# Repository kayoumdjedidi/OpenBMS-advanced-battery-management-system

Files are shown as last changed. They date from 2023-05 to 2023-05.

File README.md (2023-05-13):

# OpenBMS: Open Source advanced Battery Management System

OpenBMS is an open source battery management system (BMS) for lithium-ion and other types of batteries up to 12V and 20V total voltage. The system monitors battery status, charges the battery as required, and most importantly, balances the cells to ensure longer lifespan and protection against undervolting. The system is suitable for various applications, including electric vehicles, renewable energy systems, and portable electronics.

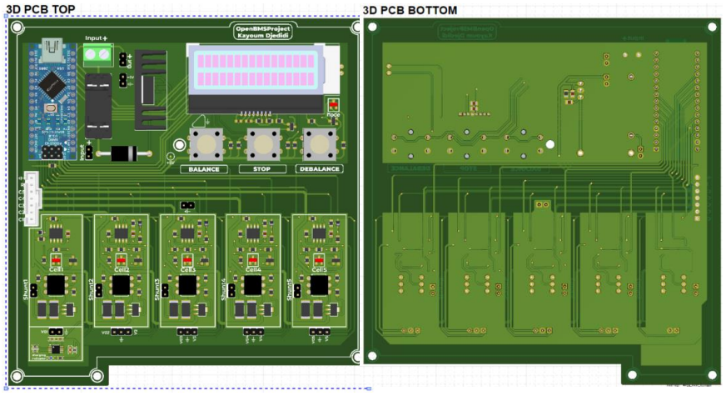
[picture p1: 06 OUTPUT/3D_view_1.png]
Preview image


## Table of Contents

- [Introduction](#openbms-open-source-battery-management-system)
- [Table of Contents](#table-of-contents)
- [Features](#features)
- [Documentation](#documentation)
- [Hardware Design](#hardware-design)
- [Software Design](#software-design)
- [Limitations and Future Improvements](#limitations-and-future-improvements)
- [License](#license)

## Features

- Cell voltage measurement, balancing, and charging circuits
- Limiter to limit the charging current to 1A when a cell is balancing
- Display module with an i2c LCD display
- Control module with a power regulator and an Arduino Nano controller
- Support for various types of batteries up to 12V and 20V total voltage
- Modular design for easy addition or removal of cells
- Double-layered PCB design using CEM methods
- Instant cut-off of input or output from the battery upon detecting unusual behavior
- Warning LEDs and charge indicator LEDs for user convenience

## Documentation

For more detailed information about the OpenBMS project, please refer to the following resources:

- [Project report in PDF format](https://github.com/kayoumdjedidi/OpenBMS-advanced-battery-management-system/blob/main/OpenBMS_project_report.pdf)
- [Schematics](https://github.com/kayoumdjedidi/OpenBMS-advanced-battery-management-system/tree/main/01%20SCH)
- [BOM and output Files](https://github.com/kayoumdjedidi/OpenBMS-advanced-battery-management-system/tree/main/06%20OUTPUT)
- [Arduino code](https://github.com/kayoumdjedidi/OpenBMS-advanced-battery-management-system/tree/main/code)

## Hardware Design

The OpenBMS PCB design was created using Altium Designer and is modular, allowing for the addition or removal of cells as required. The board is double-layered and uses CEM methods, making it suitable for use with a range of battery types.

## Software Design

The OpenBMS system is powered by an Arduino Nano controller and is programmed using Arduino. The system constantly monitors battery parameters and instantly cuts off the input or output from the battery as soon as any unusual behavior is detected. The system also includes warning LEDs and charge indicator LEDs for user convenience.

## Limitations and Future Improvements

The OpenBMS project is a work in progress, and there are several limitations and future improvements to consider, such as:

- The system currently supports up to 12V and 20V total voltage, but it could be expanded to support higher voltages.
- The charging module could be improved to provide more flexibility in charging parameters.
- The display module could be enhanced to provide more detailed information about battery status.
- The code could be optimized for better performance and efficiency.

## License

The OpenBMS project is released under the [MIT License](https://github.com/kayoumdjedidi/OpenBMS-advanced-battery-management-system/blob/main/LICENSE). You are free to use, modify, and distribute the project as long as you include the license file in your distribution.

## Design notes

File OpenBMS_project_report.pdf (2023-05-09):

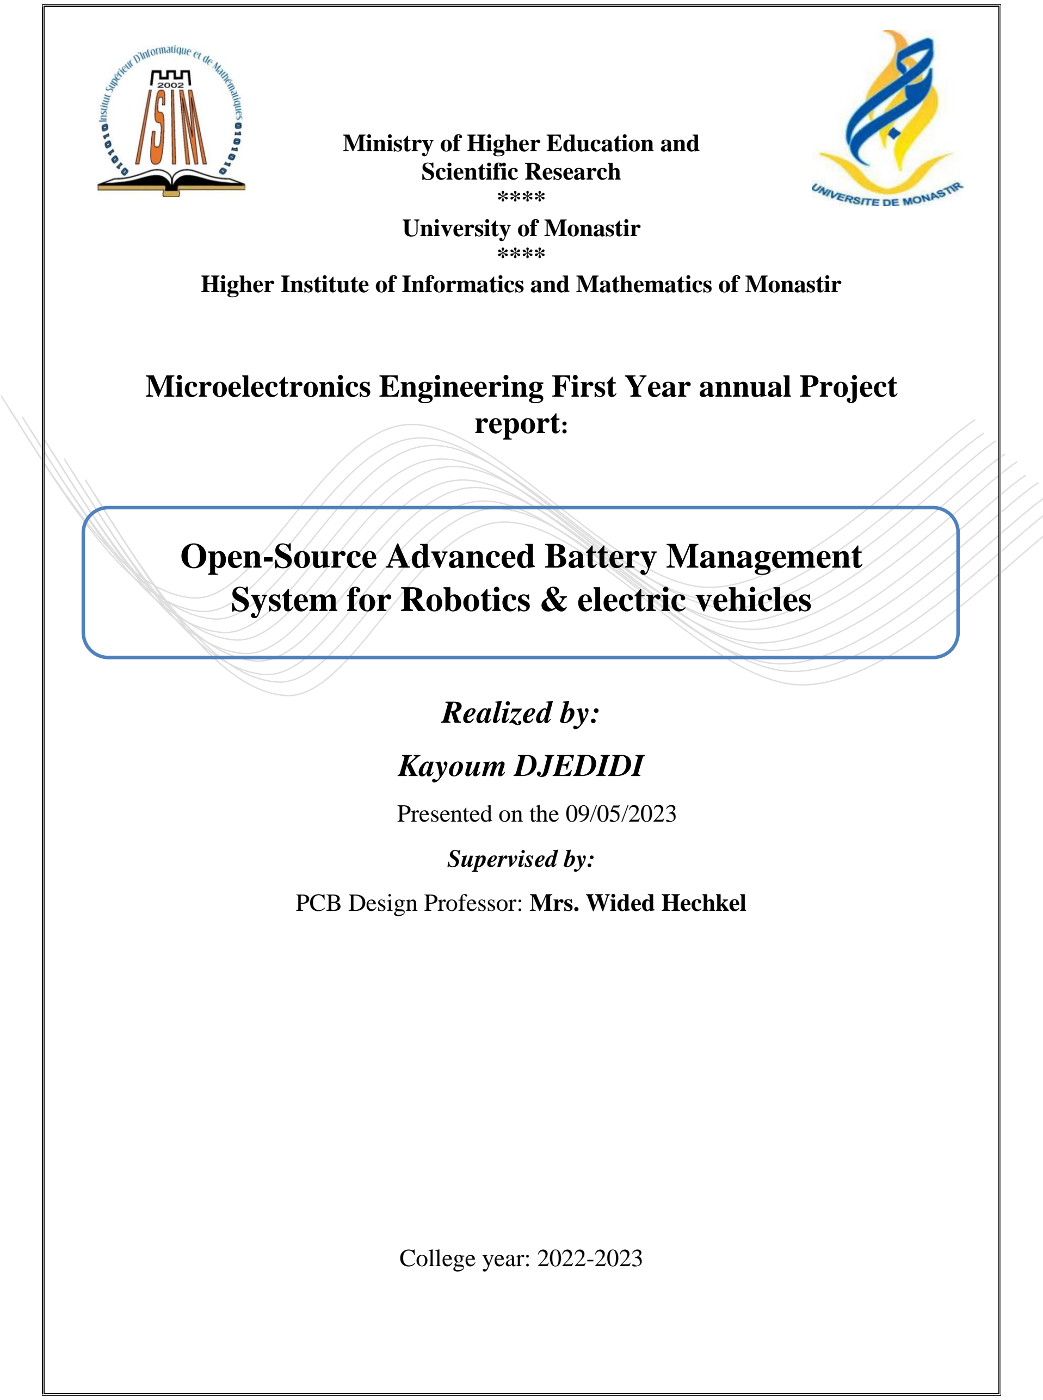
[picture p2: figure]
Ministry of Higher Education and Scientific Research **** University of Monastir ****; report:; Open-Source Advanced Battery Management System for Robotics & electric vehicles; Realized by:; Kayoum DJEDIDI; Presented on the 09/05/2023; Supervised by:; College year: 2022-2023

Higher Institute of Informatics and Mathematics of Monastir

## Microelectronics Engineering First Year annual Project

### PCB Design Professor: Mrs. Wided Hechkel

Open-Source Advanced Battery Management System for Robotics & electric vehicles

Kayoum DJEDIDI | 2

# Abstract

his report outlines the development of an open-source battery management system (BMS)

designed for use in electric vehicles and robotics platforms. The BMS was designed using

Altium Designer for creating schematics and PCB layouts, while the software was developed

using the Arduino IDE and deployed on an Arduino Nano MCU. The primary aim of this project

was to explore the latest advancements in BMS technology and to gain experience using

advanced Electronics CAD tools like Altium. This report provides a detailed overview of the

BMS design and its various features, with an emphasis on its potential applications in the fields

of electric vehicles and robotics.

Index Terms: BMS (Battery management System), CAD ( computer aided design), Altium

Designer, Arduino, electric vehicles, robotics.

T

# Table of Contents

Abstract | 2
General introduction | 4
I. Brief Overview: | 4
II. Design & Development: | 4

### 1. Description of OpenBMS | 4

### 2. PCB Design | 6

### 2.1. Schematics | 6

### 2.1.1. MCU & Power management Schematic | 6

### 2.1.2. Charging Circuit Schematic | 7

### 2.1.3. Balancing Circuit Schematic | 8

### 2.1.4. Measuring Circuit Schematic | 8

### 2.1.5. Display Circuit Schematic | 10

### 2.2. PCB | 10

### 2.2.1. Specifications and Design rules | 10

### 2.2.2. PCB Design | 11

### 3. Programming | 14

III. Conclusions | 15
Bibliography | 17

# Table of Figures

Figure 1. OpenBMS System Diagram | 6
Figure 2. Main System Schematic | 6
Figure 3. MCU & Power management schematic | 7
Figure 4. Charging circuit schematic | 7
Figure 5. Balancing Circuit Schematic | 8
Figure 6. Measuring Circuit Schematic | 9
Figure 7. Display Circuit schematic | 10
Figure 8. Final assembly PCB in 2D top view | 11
Figure 9. PCB 3D Top & Bottom Views | 11
Figure 10. PCB Highlights | 12
Figure 11. BOM | 13
Figure 12. Main code & Balancing mode flowcharts | 14

## General introduction

## I. Brief Overview:

attery Management Systems (BMS) are electronic systems designed to manage and

monitor batteries, ensuring their optimal performance and safety. BMS are widely used

in various applications, including electric vehicles, renewable energy systems, and portable

electronics, to name a few.

The primary functions of a BMS are to protect the battery from overcharging, over-discharging,

and overheating, which can lead to a decrease in battery life and, in extreme cases, pose a safety

hazard. A BMS achieves this by monitoring various battery parameters, such as voltage, and

current, and taking appropriate actions based on the measured values.

BMSs come in various types, including passive, active, and hybrid. Passive BMSs rely on

passive balancing techniques to balance the individual cells in a battery pack, while active

BMSs use active balancing techniques. Hybrid BMSs combine the advantages of both passive

and active balancing techniques.

In recent years, there has been a growing interest in open-source BMSs, as they offer greater

transparency, flexibility, and cost-effectiveness compared to proprietary solutions. Open-source

BMSs allow users to modify and customize the system according to their needs and provide a

platform for collaboration and knowledge-sharing among the maker community.

The purpose of this report is to document the process of designing, developing, and testing the

Open Source BMS System. The report will cover the various aspects of the project, including

the design and development of the BMS PCB using Altium Design, and coding of the BMS

using Arduino. The report will also provide a comparison of the Open Source BMS System

with other commercial BMS systems, as well as its limitations and future improvements.

The report aims to serve as a guide for anyone interested in designing and developing their own

BMS system, as well as to promote the use of Open Source hardware and software.

## II.Design & Development:

## 1. Description of OpenBMS

he Open Source Battery Management System (OpenBMS) for Lithium Cells is a system

designed to Monitor battery status and display it, charge the battery as required, and most

B

T

importantly, balance the cells, insuring a longer lifespan, as well as protecting them from under-

volting. The system can also prepare the cells for permanent storage.

OpenBMS is suitable for Lithium-ion, Lithium Iron Phosphate (Lifepo4), Nickel Cadmium

(NiCd), Nickel-Metal Hydride (NiMH), Lead Acid (flooded, VRLA, SLA) batteries up to 12V,

and other types such as NiZn, alkaline, etc., with a total voltage of up to 20V.A

The Open Source BMS System consists of several modules, including the Cell Module,

containing the voltage measure, balance, and charge circuits, the Limiter, a display Module in

the form of an i2c LCD display, and a control module in the form of a power regulator and

MCU.

The Cell Module is responsible for monitoring the voltage of each cell in the battery pack, and

the Control Unit processes this information and controls the operation of the Limiter and

charging. The Limiter limits the charging current to 1A when a cell in the pack is balancing,

and the Charging Module charges the battery pack according to the required battery parameters.

The PCB design was created using Altium Design, and is modular, allowing for the addition or

removal of cells as required. The board is double-layered and uses CEM methods, making it

suitable for use with a range of battery types.

The BMS system is powered by an Arduino Nano controller and is programmed using Arduino.

The system constantly monitors battery parameters, and instantly cuts off the input or output

from the battery as soon as any unusual behavior is detected. The system also includes warning

LEDs and charge indicator LEDs for user convenience.

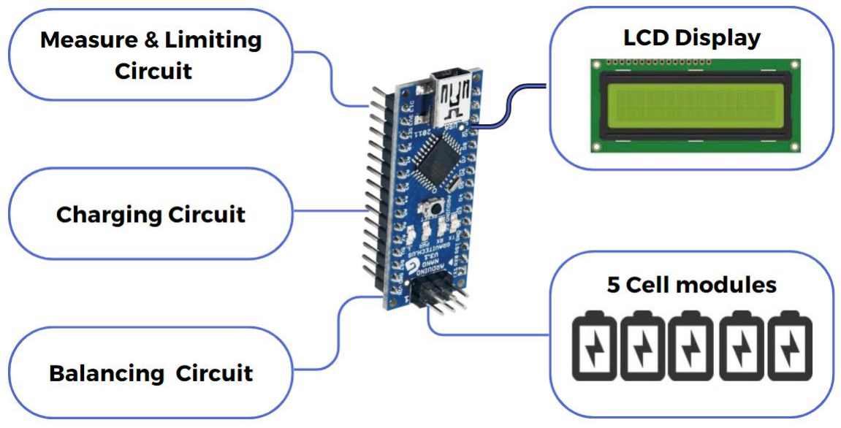
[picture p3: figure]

FIGURE 1. OPENBMS SYSTEM DIAGRAM

## 2. PCB Design

## 2.1. Schematics

We have used the Multi-sheet & Hierarchical approach [1] when it comes to organizing the different parts of this system, all the schematics are grouped and connected to the Top layer called OpenBms.SCHDOC, This is done via the “create sheet from sheet symbol tool.

The figure below showcases how the different modules are connected, on the left we can see a hypothetical indication showing how batteries must be connected to the system. Inspiration for tis approach was taken from the community [2].

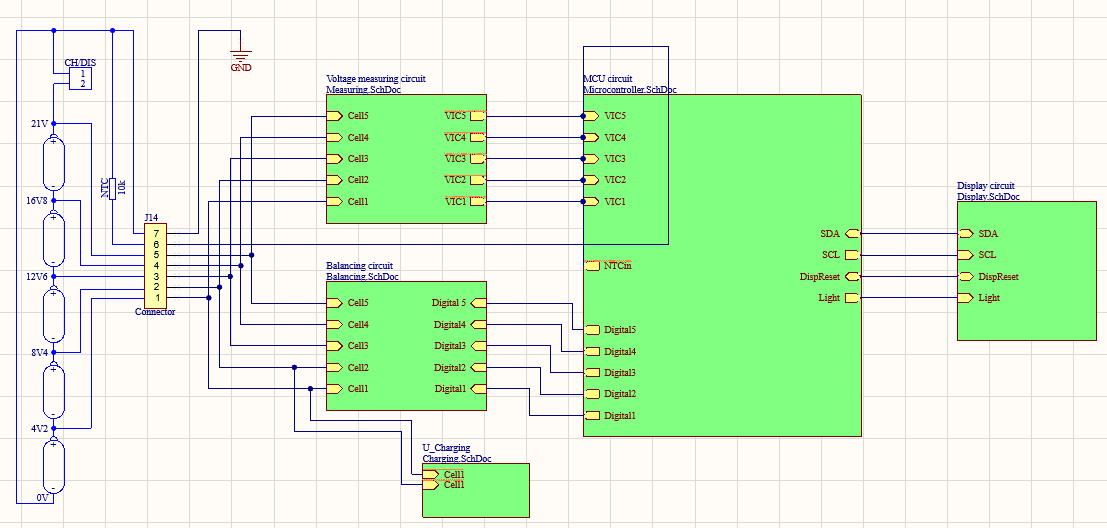
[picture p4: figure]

FIGURE 2. MAIN SYSTEM SCHEMATIC

## 2.1.1. MCU & Power management Schematic

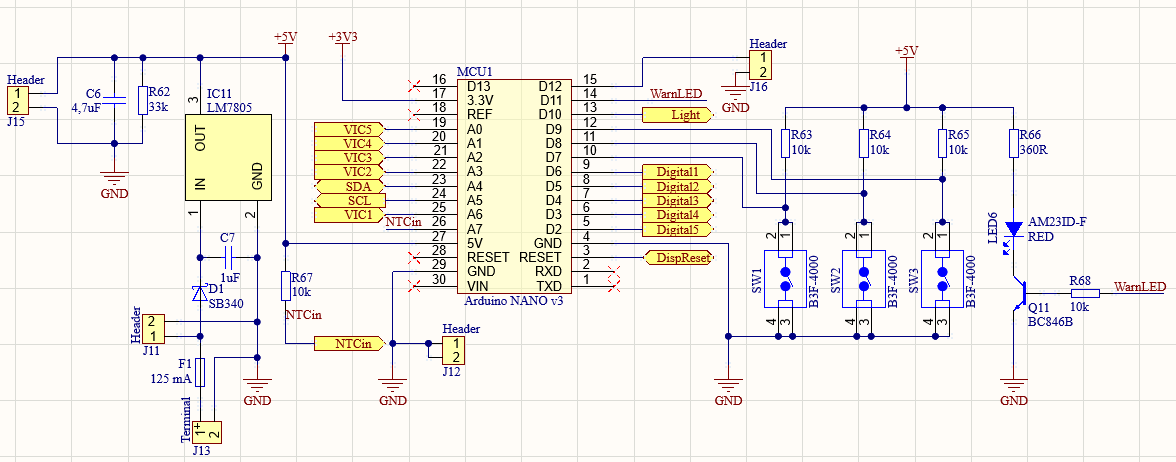
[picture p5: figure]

FIGURE 3. MCU & POWER MANAGEMENT SCHEMATIC

The Figure above highlights the first part of our system, here we are using a regular header,

along with some regular input connectors to take the external power source, and then we take

the power through a filtering & regulation stage, for it to finally be distributed to the whole

system. The necessary MCU pins are also connected, and 3 buttons are provided in order to

cycle between the different operating modes.

The regulation circuit design was taken from a reliable source online, as it is simple and non-

expensive.

## 2.1.2. Charging Circuit Schematic

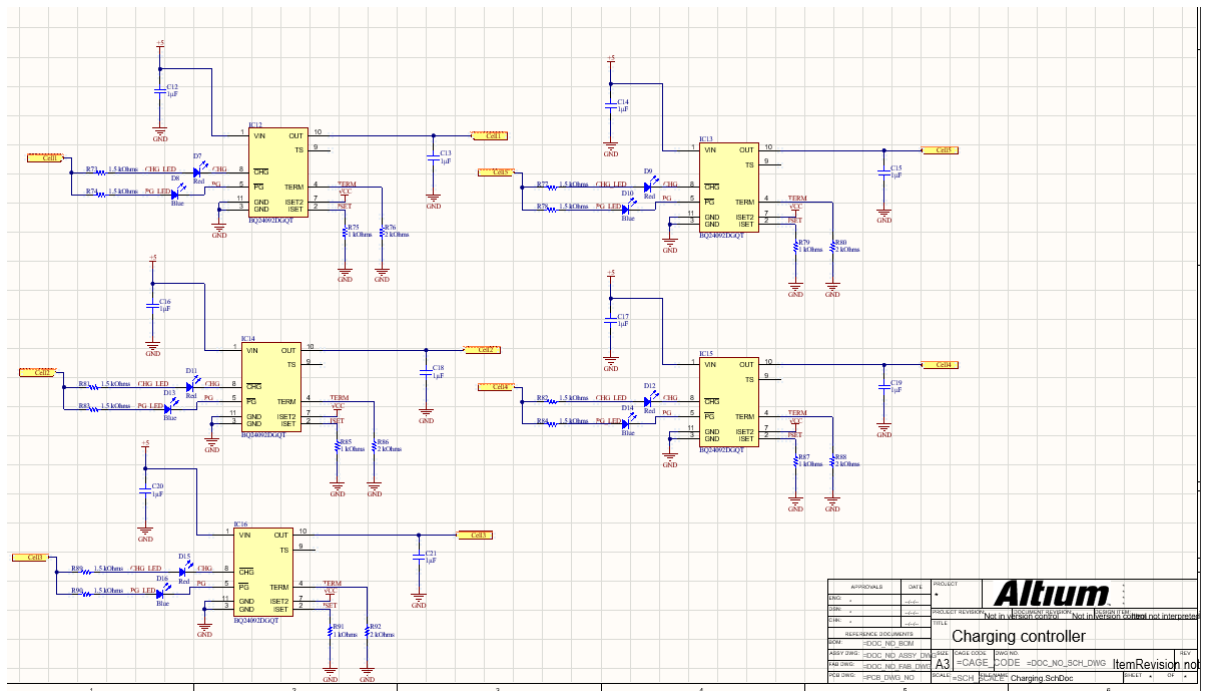
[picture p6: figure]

FIGURE 4. CHARGING CIRCUIT SCHEMATIC

In the figure above, you can see a simple charging & charge indication circuit, which is

duplicated for each of the cells of our system( to be showcased later).

This will be a common theme in the rest of the project, since it’s modular, meaning that you

can keep on duplicating the modules for the number of requested total cells. In this case, the

system can support five cells at once.

This circuit is based on the BQ24092DGQT IC, which takes our regulated input and makes sure

to correctly charge the battery; it comes after the balancing & voltage measurement stages,

assuring correct charging.

## 2.1.3. Balancing Circuit Schematic

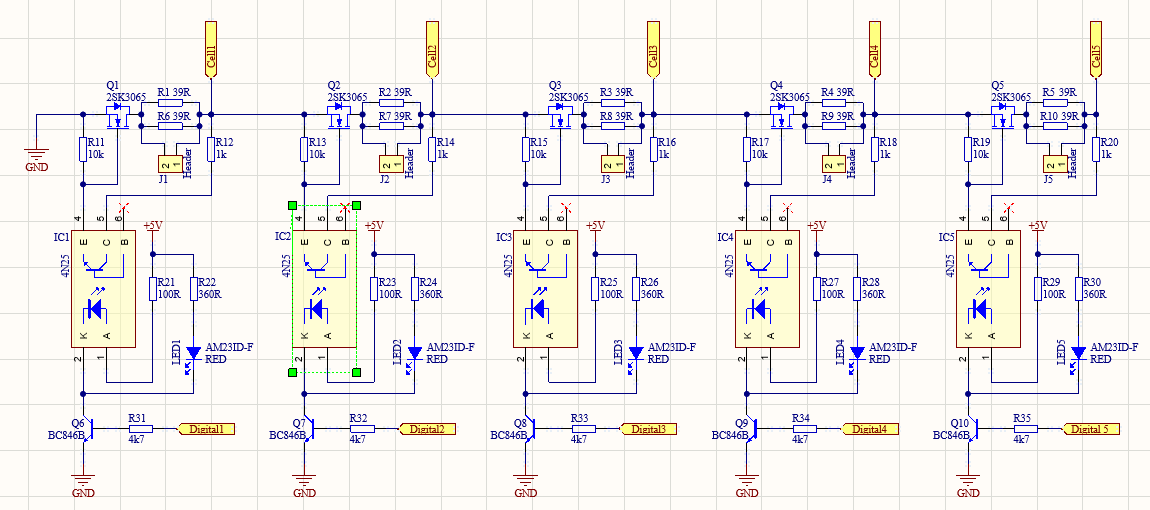
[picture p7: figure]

FIGURE 5. BALANCING CIRCUIT SCHEMATIC

Here, you can see the five duplicated modules, each them Is based on the 4N25 Optocoupler,

which will help us reduce noise, and most importantly, isolate Low-voltage devised from high

voltage circuits, allowing us to compare the cells and identity miss-balanced ones.

We used extra headers here to insure the functionality of probing, to facilitate testing and

debugging the system when needed.

## 2.1.4. Measuring Circuit Schematic

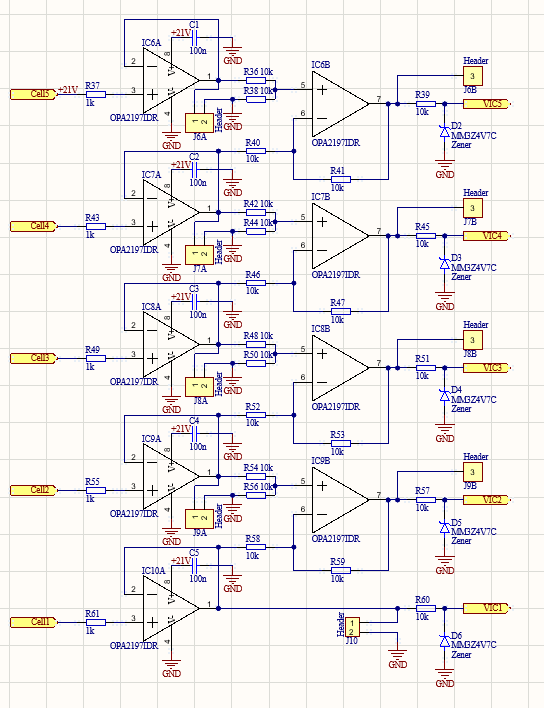
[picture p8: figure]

FIGURE 6. MEASURING CIRCUIT SCHEMATIC

This circuit is used to sense voltage and current, thus making sure the batteries are safe and

protected, is uses two OPAx197 Dual 36-V, precision, rail-to-rail input output, low offset

voltage op amps [3].

The Unique features of this amp, such as the differential input-voltage range to the supply rail,

high output current (±65 mA), high capacitive load drive of up to 1 nF, and high slew rate (20

V/µs) make the OPA197 a robust, high-performance operational amplifier for high-voltage,

industrial applications.

## 2.1.5. Display Circuit Schematic

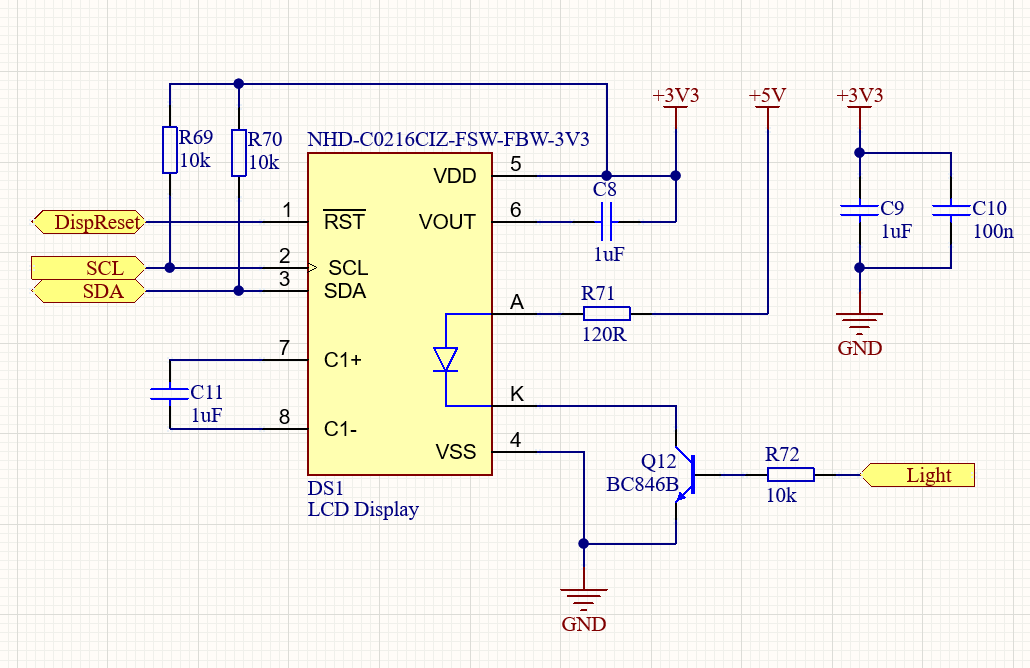
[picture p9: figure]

FIGURE 7. DISPLAY CIRCUIT SCHEMATIC

Here, we have the final schematic of our system, which is the simple connection to the LCD

Display, with resistors and capacitors added in order to clean the signals, and a connection to

the light indicator. The multi-layer approach allowed us to facilitate the feat of creating

schematics, by giving us breathable space, and a clear visual experience; also, it improves

readability and thus rendering the project more suitable for collaborations.

## 2.2. PCB

## 2.2.1. Specifications and Design rules

The final board size is 133.0000mm x 136.5000mm, with 155 total components.

We used a two-layer design, one top and one bottom, with all components on the top layer, also ground area was left on both in order to improve the quality of the design and make it resilient towards outside noise, thus respecting the laws of electromagnetic compatibility.

The toal Copper Area is 16428 Sq Mms, with 63 drill pairs.

Our track width was a consistent 0.0254mm, with some exceptions when needed.

The dominant technology used is SMD, as it reduces space and improves the overall quality.

## 2.2.2. PCB Design

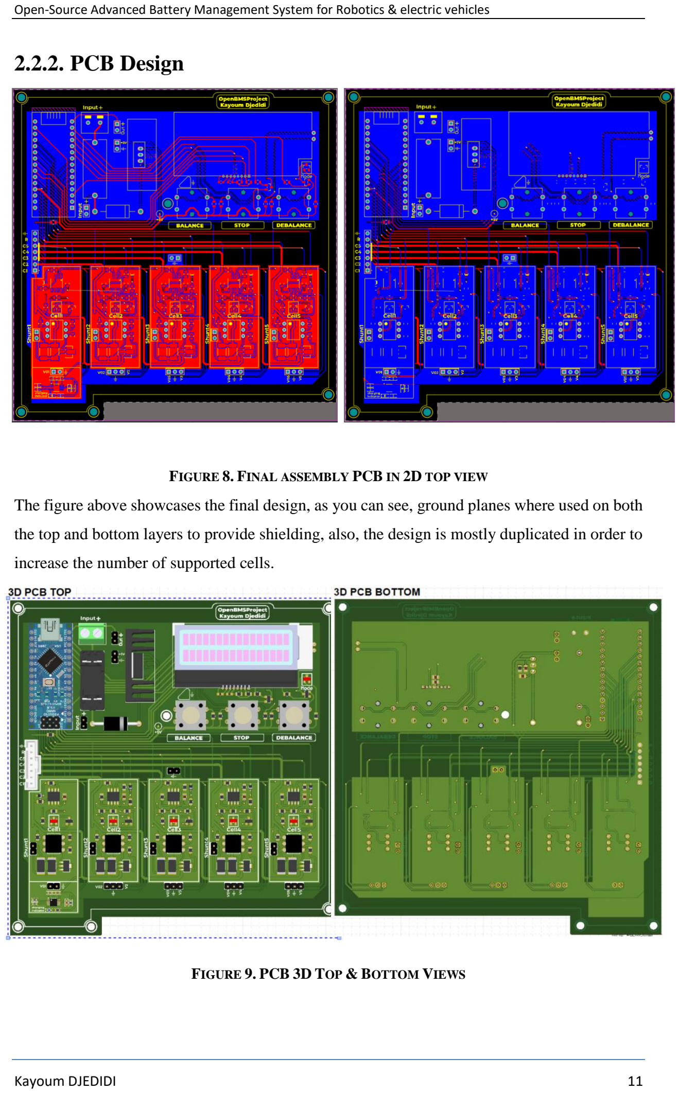
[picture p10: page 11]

FIGURE 8. FINAL ASSEMBLY PCB IN 2D TOP VIEW

The figure above showcases the final design, as you can see, ground planes where used on both

the top and bottom layers to provide shielding, also, the design is mostly duplicated in order to

increase the number of supported cells.

FIGURE 9. PCB 3D TOP & BOTTOM VIEWS

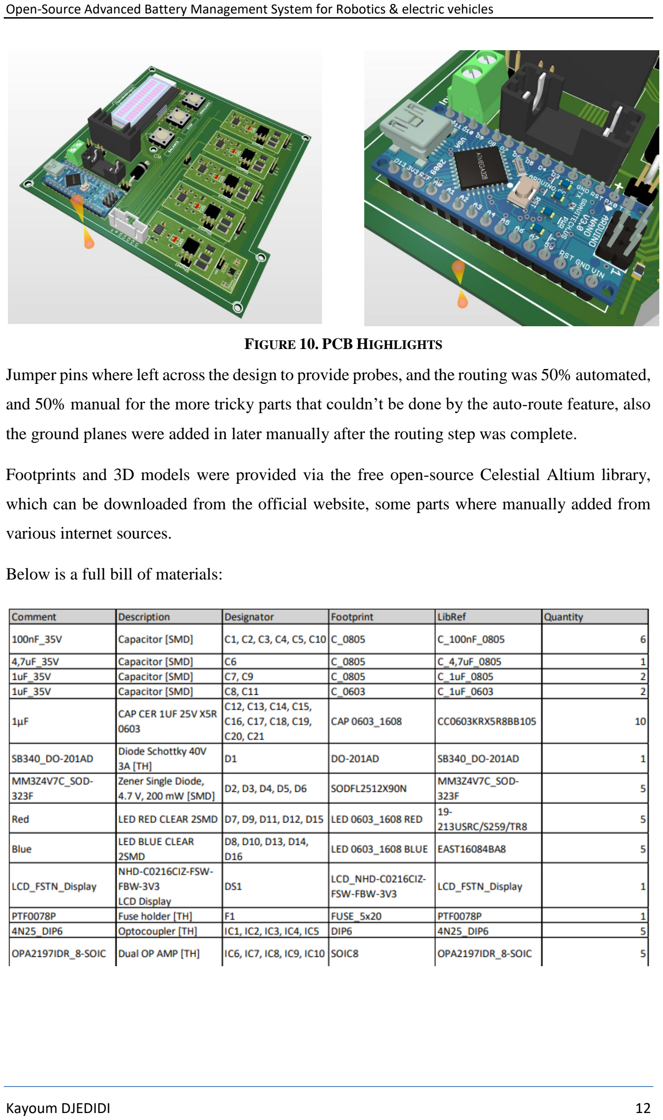
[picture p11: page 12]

Jumper pins where left across the design to provide probes, and the routing was 50% automated,

and 50% manual for the more tricky parts that couldn’t be done by the auto-route feature, also

the ground planes were added in later manually after the routing step was complete.

Footprints and 3D models were provided via the free open-source Celestial Altium library,

which can be downloaded from the official website, some parts where manually added from

various internet sources.

Below is a full bill of materials:

FIGURE 10. PCB HIGHLIGHTS

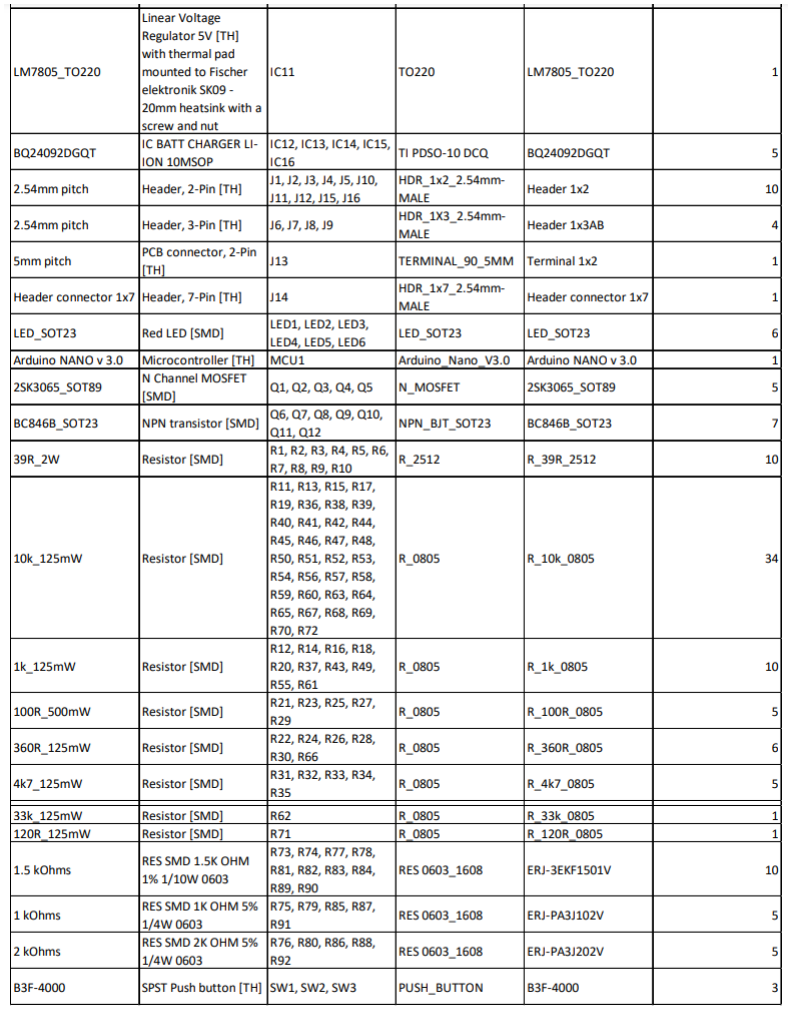
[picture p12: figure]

Draftsman document and an Output project PDF file generated using Altium with further details

can be found in the project source files.

FIGURE 11. BOM

## 3. Programming

The code was developed using C++ with the Arduino IDE, We took a lot of inspiration from

other resources found online [4], especially for necessary calculations and methods used, such

as the usage of the MCU timers in order to do most functions.

Note that while it is functional and serves all the basic needs, it is still very not well optimized

since we could not test it in a real world scenario. Future versions will focus on reducing

unnecessary clutter and improving precision.

The diagrams below explain the code functionality in detail:

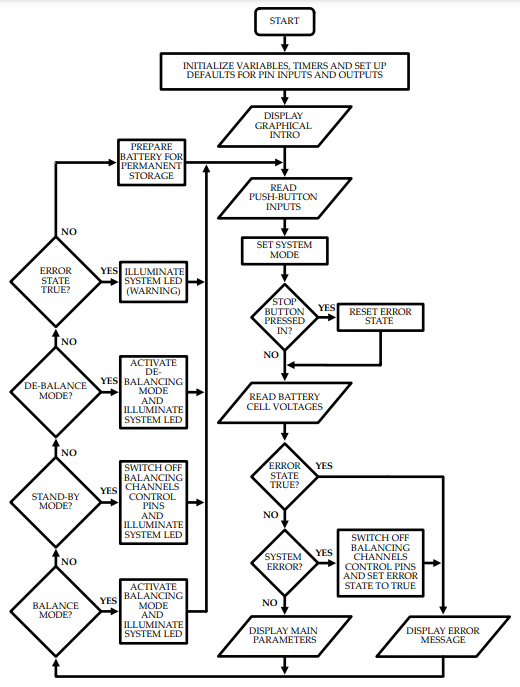
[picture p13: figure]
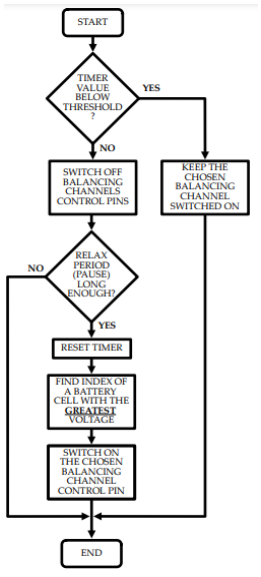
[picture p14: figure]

FIGURE 12. MAIN CODE & BALANCING MODE FLOWCHARTS

## III. Conclusions

Compared to existing [5] [6] commercial BMS systems, this open-source BMS offers a more

flexible and customizable solution, as well as a lower cost. While commercial BMS systems

typically have a fixed set of features and may not be suitable for all applications, this open-

source BMS allows users to modify and adapt the system to their specific needs. Additionally,

commercial BMS systems can be expensive, while this open-source BMS offers a cost-effective

solution for makers and hobbyists. However, there are also some disadvantages to this BMS

system. One potential disadvantage is the level of technical expertise required to modify and

adapt the system, which may be challenging for some users. Additionally, the open-source

nature of the system means that there may be limited technical support available, although the

community can provide assistance and guidance.

One limitation of this BMS system is that it is designed to work with specific types of batteries,

including Li-ion, Li-Po, LiFePO4, NiCd, NiMH, and lead-acid batteries, with a maximum

voltage of 20V. This may limit its use in certain applications that require other types of batteries

or higher voltages.

Areas for improvement include expanding the range of compatible battery types and voltages,

improving the documentation and technical support for the system, and further optimizing the

software for better performance and reliability. Additionally, adding features such as wireless

communication and remote monitoring could enhance the usability and flexibility of the BMS

system.

In conclusion, the open-source advanced battery management system designed in this project

provides an affordable and efficient solution for the management and protection of batteries

used in electric vehicles and robotics platforms.

The system was designed using the Altium Designer tool set, with the software developed on

an Arduino Nano MCU, and it features a number of important functions such as overvoltage

protection, under voltage protection, cell balancing, and charging current limitation.

Through a comparison with existing BMS systems [7], it was found that the open-source BMS

system offers similar performance at a much lower cost, making it a viable option for makers

and DIY enthusiasts.

Overall, this project serves as a valuable exploration of BMS systems and a useful tool for

learning about electronics CAD tools such as Altium, as well as providing a low-cost and

effective solution for battery management and protection.

# Bibliography

[1] "Multi-sheet & Hierarchical Designs in Altium Designer," Altium, [Online]. Available: https://www.altium.com/documentation/altium-designer/multi-sheet-multi-channeldesign?version=18.1.
[2] "SmartBMS," Github, [Online]. Available: https://github.com/Green-bms/SmartBMS.
[3] "OPA2197," Texas instrument, [Online]. Available: https://www.ti.com/product/OPA2197#description.
[4] "Arduino LTC6804 BMS - Part 1: Main Board : 9 Steps," Instructables, [Online]. Available: https://www.google.com/url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.
[5] e. a. P. V. H. T. Jayathilake, "A review of battery management systems in electric vehicles and their requirements," 2018.
[6] S. S. S. S. a. S. Rajakumar, "Design and Implementation of a Battery Management System for a Lithium-Ion Battery Pack," 2020.
[7] " Lithium Ion Battery Management and Protection Module (BMS ) Teardown," Circuit Digest, [Online]. Available: https://circuitdigest.com/electronic-circuits/lithium-ion-batterymanagement-and-protection-module-bms-teardown-schematics-parts-list-and-working.

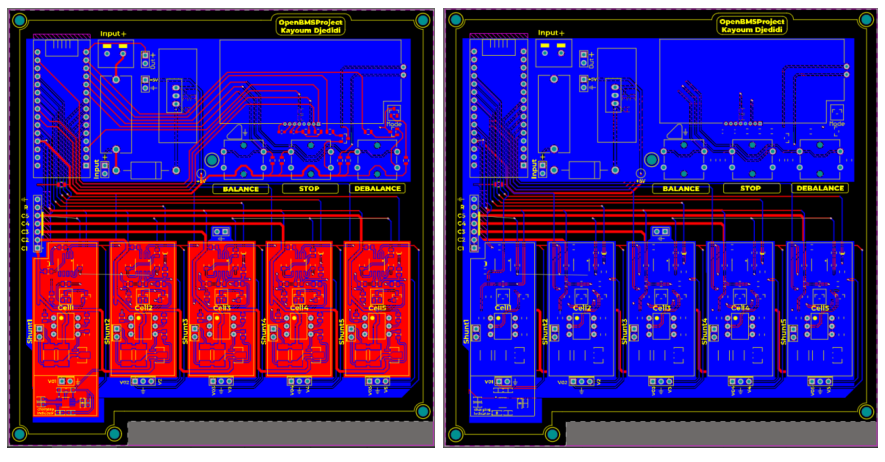
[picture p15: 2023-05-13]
06 OUTPUT/Schematic_view.png

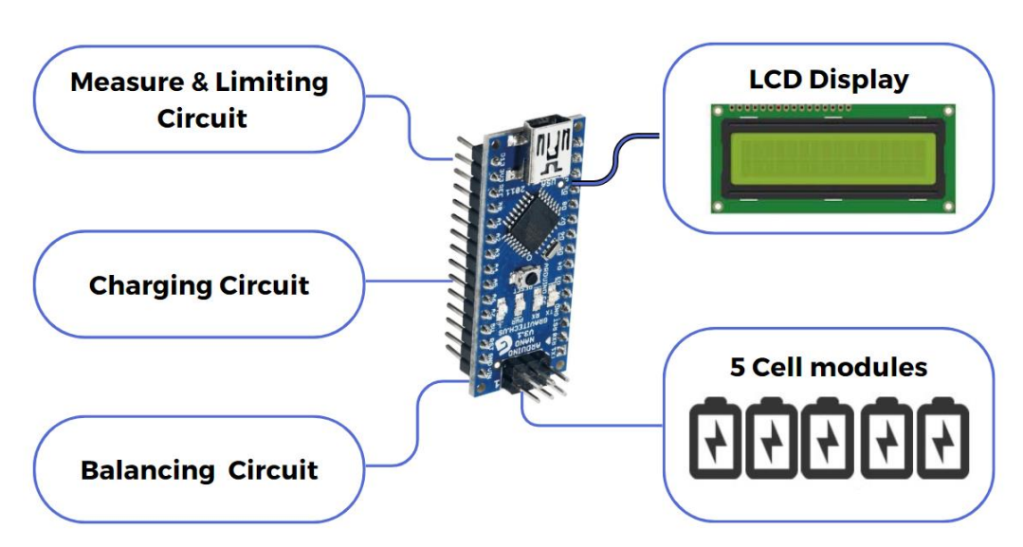
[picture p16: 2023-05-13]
06 OUTPUT/System_view.png

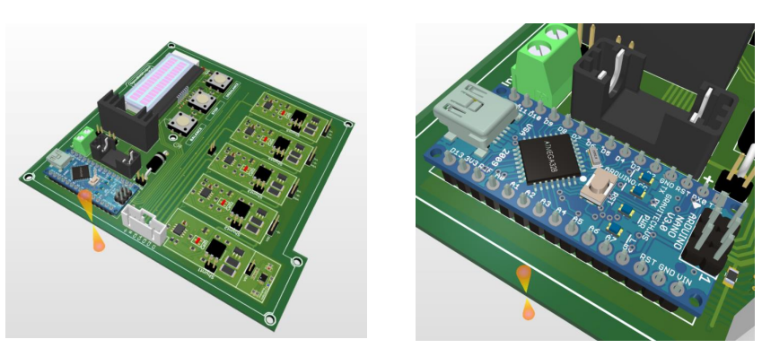
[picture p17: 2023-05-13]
06 OUTPUT/3D_View.png

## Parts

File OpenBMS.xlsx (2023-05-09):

Comment | Description | Designator | Footprint | LibRef | Quantity
100nF_35V | Capacitor [SMD] | C1, C2, C3, C4, C5, C10 | C_0805 | C_100nF_0805 | 6
4,7uF_35V | Capacitor [SMD] | C6 | C_0805 | C_4,7uF_0805 | 1
1uF_35V | Capacitor [SMD] | C7, C9 | C_0805 | C_1uF_0805 | 2
1uF_35V | Capacitor [SMD] | C8, C11 | C_0603 | C_1uF_0603 | 2
1µF | CAP CER 1UF 25V X5R 0603 | C12, C13 | CAP 0603_1608 | CC0603KRX5R8BB105 | 2
SB340_DO-201AD | Diode Schottky 40V 3A [TH] | D1 | DO-201AD | SB340_DO-201AD | 1
MM3Z4V7C_SOD-323F | Zener Single Diode, 4.7 V, 200 mW [SMD] | D2, D3, D4, D5, D6 | SODFL2512X90N | MM3Z4V7C_SOD-323F | 5
Red | LED RED CLEAR 2SMD | D7 | LED 0603_1608 RED | 19-213USRC/S259/TR8 | 1
Blue | LED BLUE CLEAR 2SMD | D8 | LED 0603_1608 BLUE | EAST16084BA8 | 1
LCD_FSTN_Display | NHD-C0216CIZ-FSW-FBW-3V3 LCD Display | DS1 | LCD_NHD-C0216CIZ-FSW-FBW-3V3 | LCD_FSTN_Display | 1
PTF0078P | Fuse holder [TH] | F1 | FUSE_5X20 | PTF0078P | 1
4N25_DIP6 | Optocoupler [TH] | IC1, IC2, IC3, IC4, IC5 | DIP6 | 4N25_DIP6 | 5
OPA2197IDR_8-SOIC | Dual OP AMP [TH] | IC6, IC7, IC8, IC9, IC10 | SOIC8 | OPA2197IDR_8-SOIC | 5
LM7805_TO220 | Linear Voltage Regulator 5V [TH] with thermal pad mounted to Fischer elektronik SK09 - 20mm heatsink with a screw and nut | IC11 | TO220 | LM7805_TO220 | 1
BQ24092DGQT | IC BATT CHARGER LI-ION 10MSOP | IC12 | TI PDSO-10 DCQ | BQ24092DGQT | 1
2.54mm pitch | Header, 2-Pin [TH] | J1, J2, J3, J4, J5, J10, J11, J12, J15, J16 | HDR_1X2_2.54MM-MALE | Header 1x2 | 10
2.54mm pitch | Header, 3-Pin [TH] | J6, J7, J8, J9 | HDR_1X3_2.54MM-MALE | Header 1x3AB | 4
5mm pitch | PCB connector, 2-Pin [TH] | J13 | TERMINAL_90_5MM | Terminal 1x2 | 1
Header connector 1x7 | Header, 7-Pin [TH] | J14 | HDR_1X7_2.54MM-MALE | Header connector 1x7 | 1
LED_SOT23 | Red LED [SMD] | LED1, LED2, LED3, LED4, LED5, LED6 | LED_SOT23 | LED_SOT23 | 6
Arduino NANO v 3.0 | Microcontroller [TH] | MCU1 | ARDUINO_NANO_V3.0 | Arduino NANO v 3.0 | 1
2SK3065_SOT89 | N Channel MOSFET [SMD] | Q1, Q2, Q3, Q4, Q5 | N_MOSFET | 2SK3065_SOT89 | 5
BC846B_SOT23 | NPN transistor [SMD] | Q6, Q7, Q8, Q9, Q10, Q11, Q12 | NPN_BJT_SOT23 | BC846B_SOT23 | 7
39R_2W | Resistor [SMD] | R1, R2, R3, R4, R5, R6, R7, R8, R9, R10 | R_2512 | R_39R_2512 | 10
10k_125mW | Resistor [SMD] | R11, R13, R15, R17, R19, R36, R38, R39, R40, R41, R42, R44, R45, R46, R47, R48, R50, R51, R52, R53, R54, R56, R57, R58, R59, R60, R63, R64, R65, R67, R68, R69, R70, R72 | R_0805 | R_10k_0805 | 34
1k_125mW | Resistor [SMD] | R12, R14, R16, R18, R20, R37, R43, R49, R55, R61 | R_0805 | R_1k_0805 | 10
100R_500mW | Resistor [SMD] | R21, R23, R25, R27, R29 | R_0805 | R_100R_0805 | 5
360R_125mW | Resistor [SMD] | R22, R24, R26, R28, R30, R66 | R_0805 | R_360R_0805 | 6
4k7_125mW | Resistor [SMD] | R31, R32, R33, R34, R35 | R_0805 | R_4k7_0805 | 5
33k_125mW | Resistor [SMD] | R62 | R_0805 | R_33k_0805 | 1
120R_125mW | Resistor [SMD] | R71 | R_0805 | R_120R_0805 | 1
1.5 kOhms | RES SMD 1.5K OHM 1% 1/10W 0603 | R73, R74 | RES 0603_1608 | ERJ-3EKF1501V | 2
1 kOhms | RES SMD 1K OHM 5% 1/4W 0603 | R75 | RES 0603_1608 | ERJ-PA3J102V | 1
2 kOhms | RES SMD 2K OHM 5% 1/4W 0603 | R76 | RES 0603_1608 | ERJ-PA3J202V | 1
B3F-4000 | SPST Push button [TH] | SW1, SW2, SW3 | PUSH_BUTTON | B3F-4000 | 3

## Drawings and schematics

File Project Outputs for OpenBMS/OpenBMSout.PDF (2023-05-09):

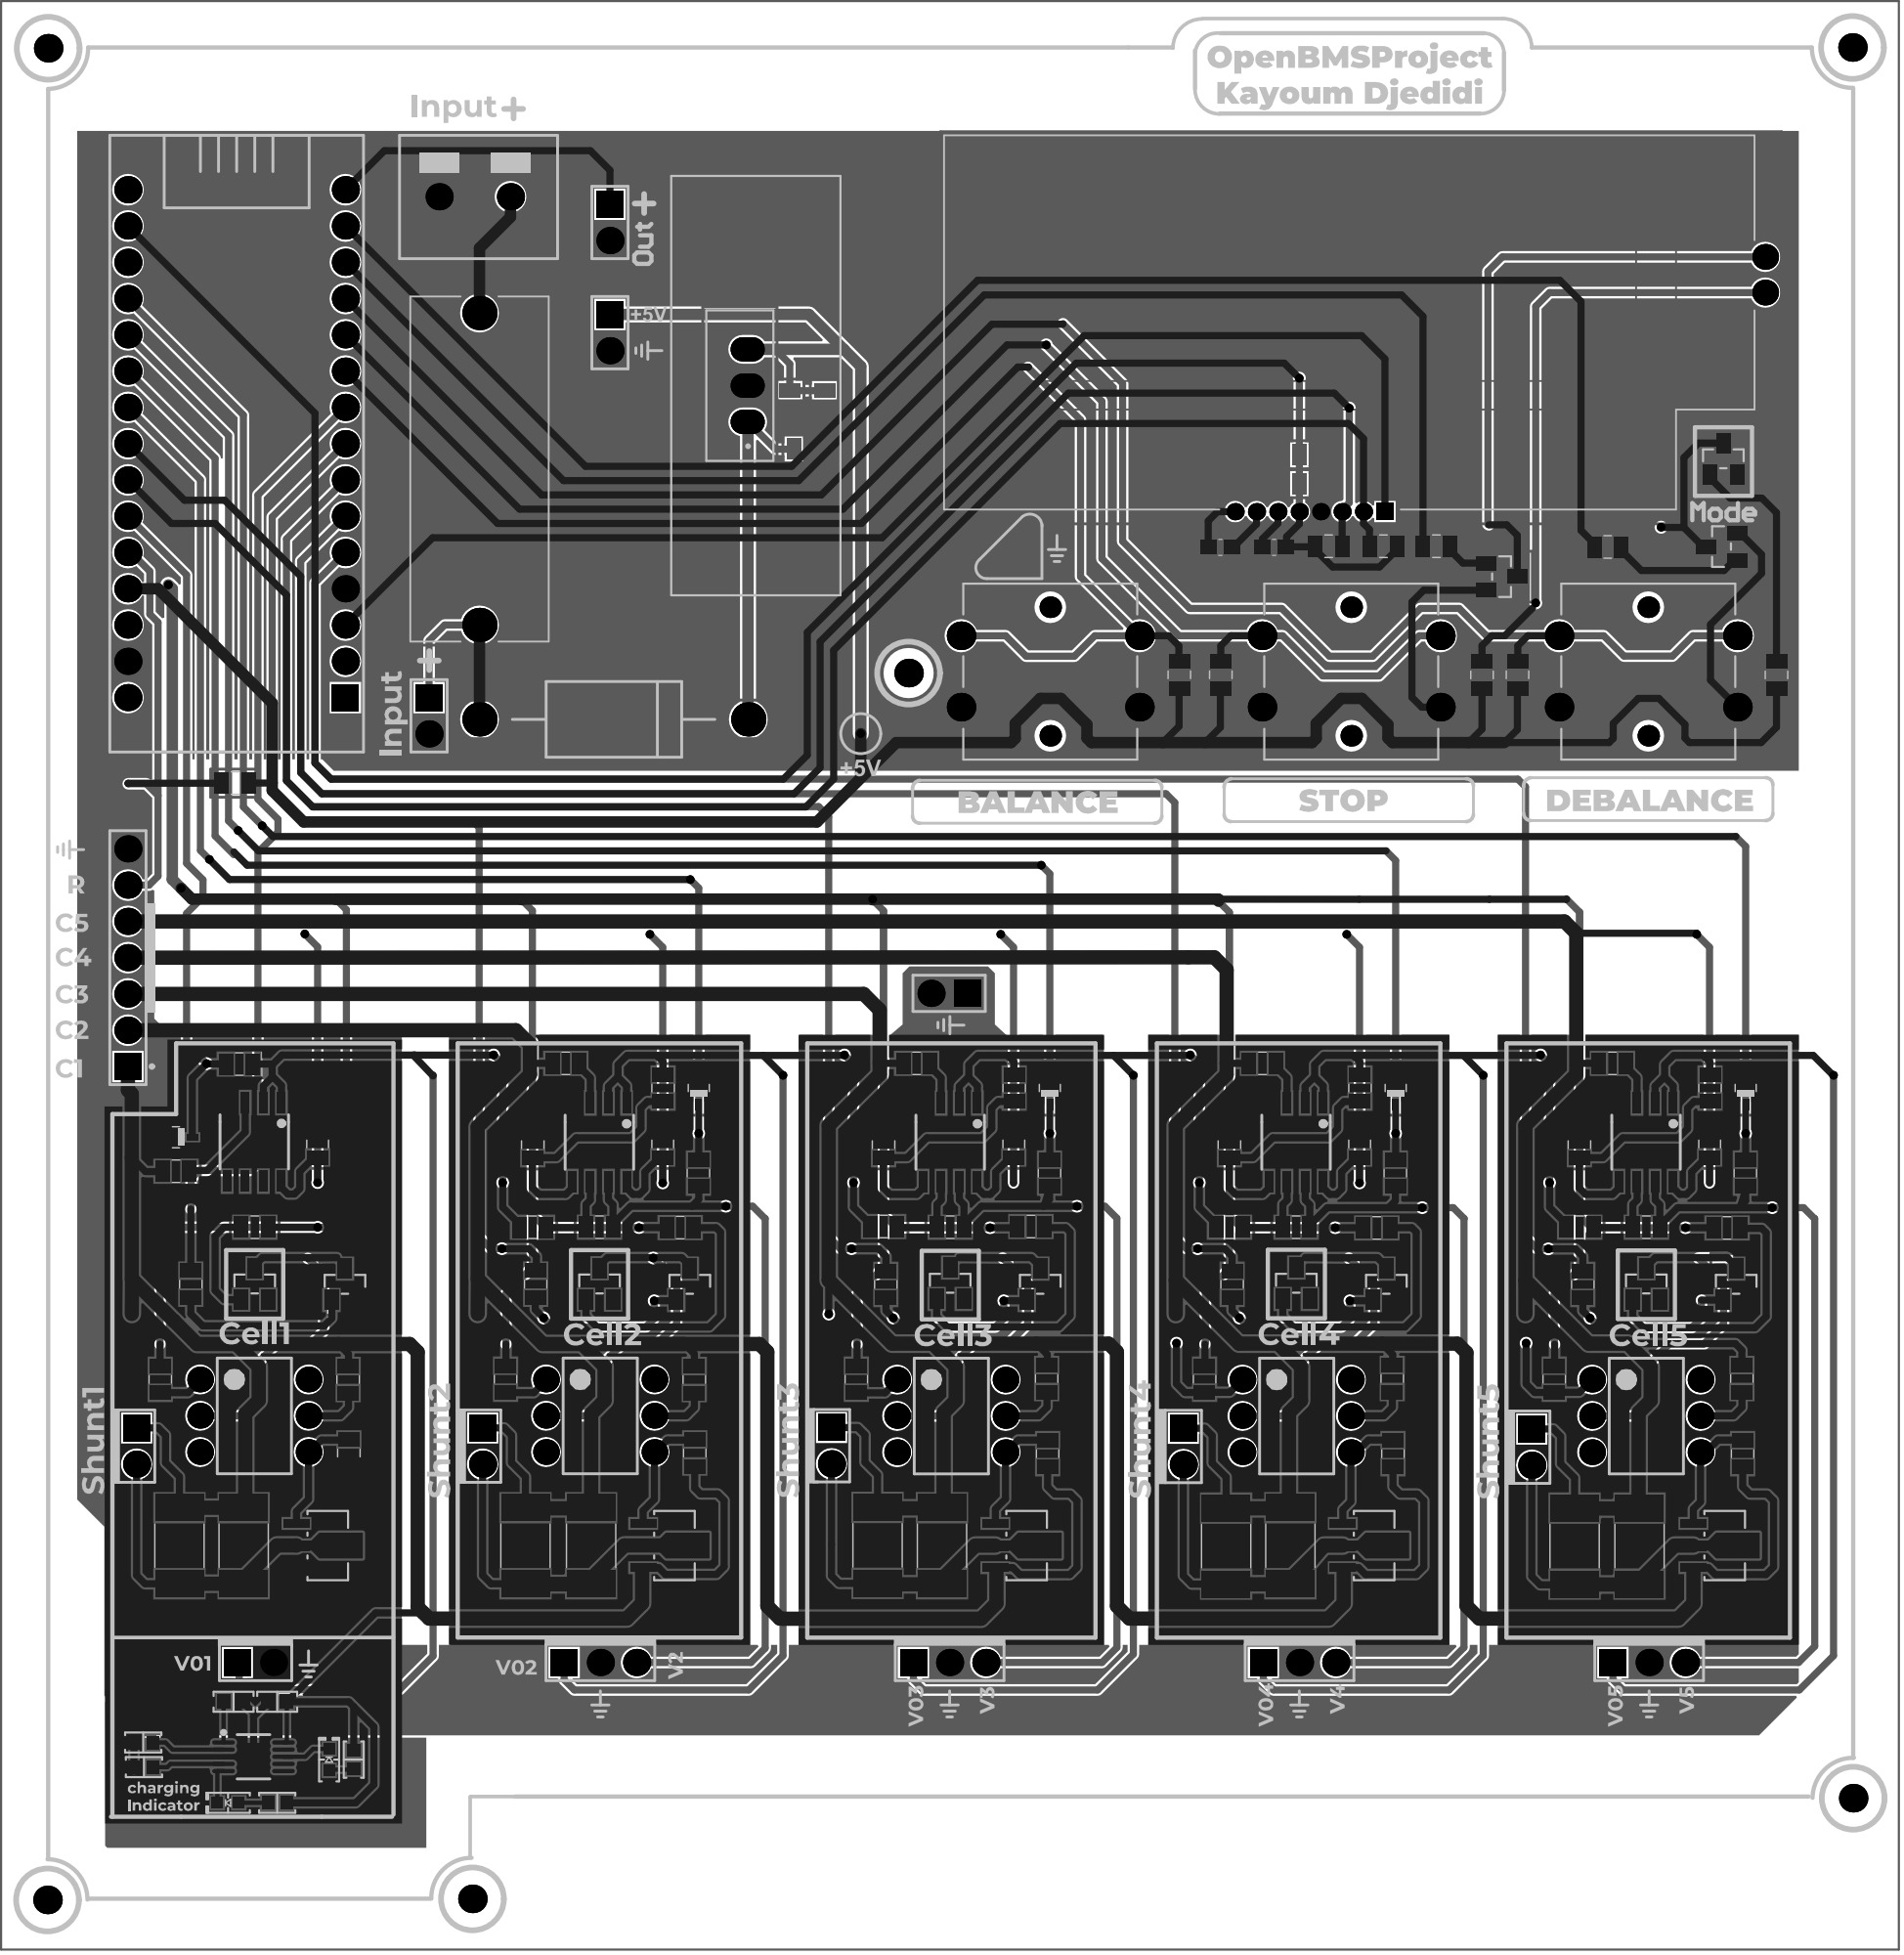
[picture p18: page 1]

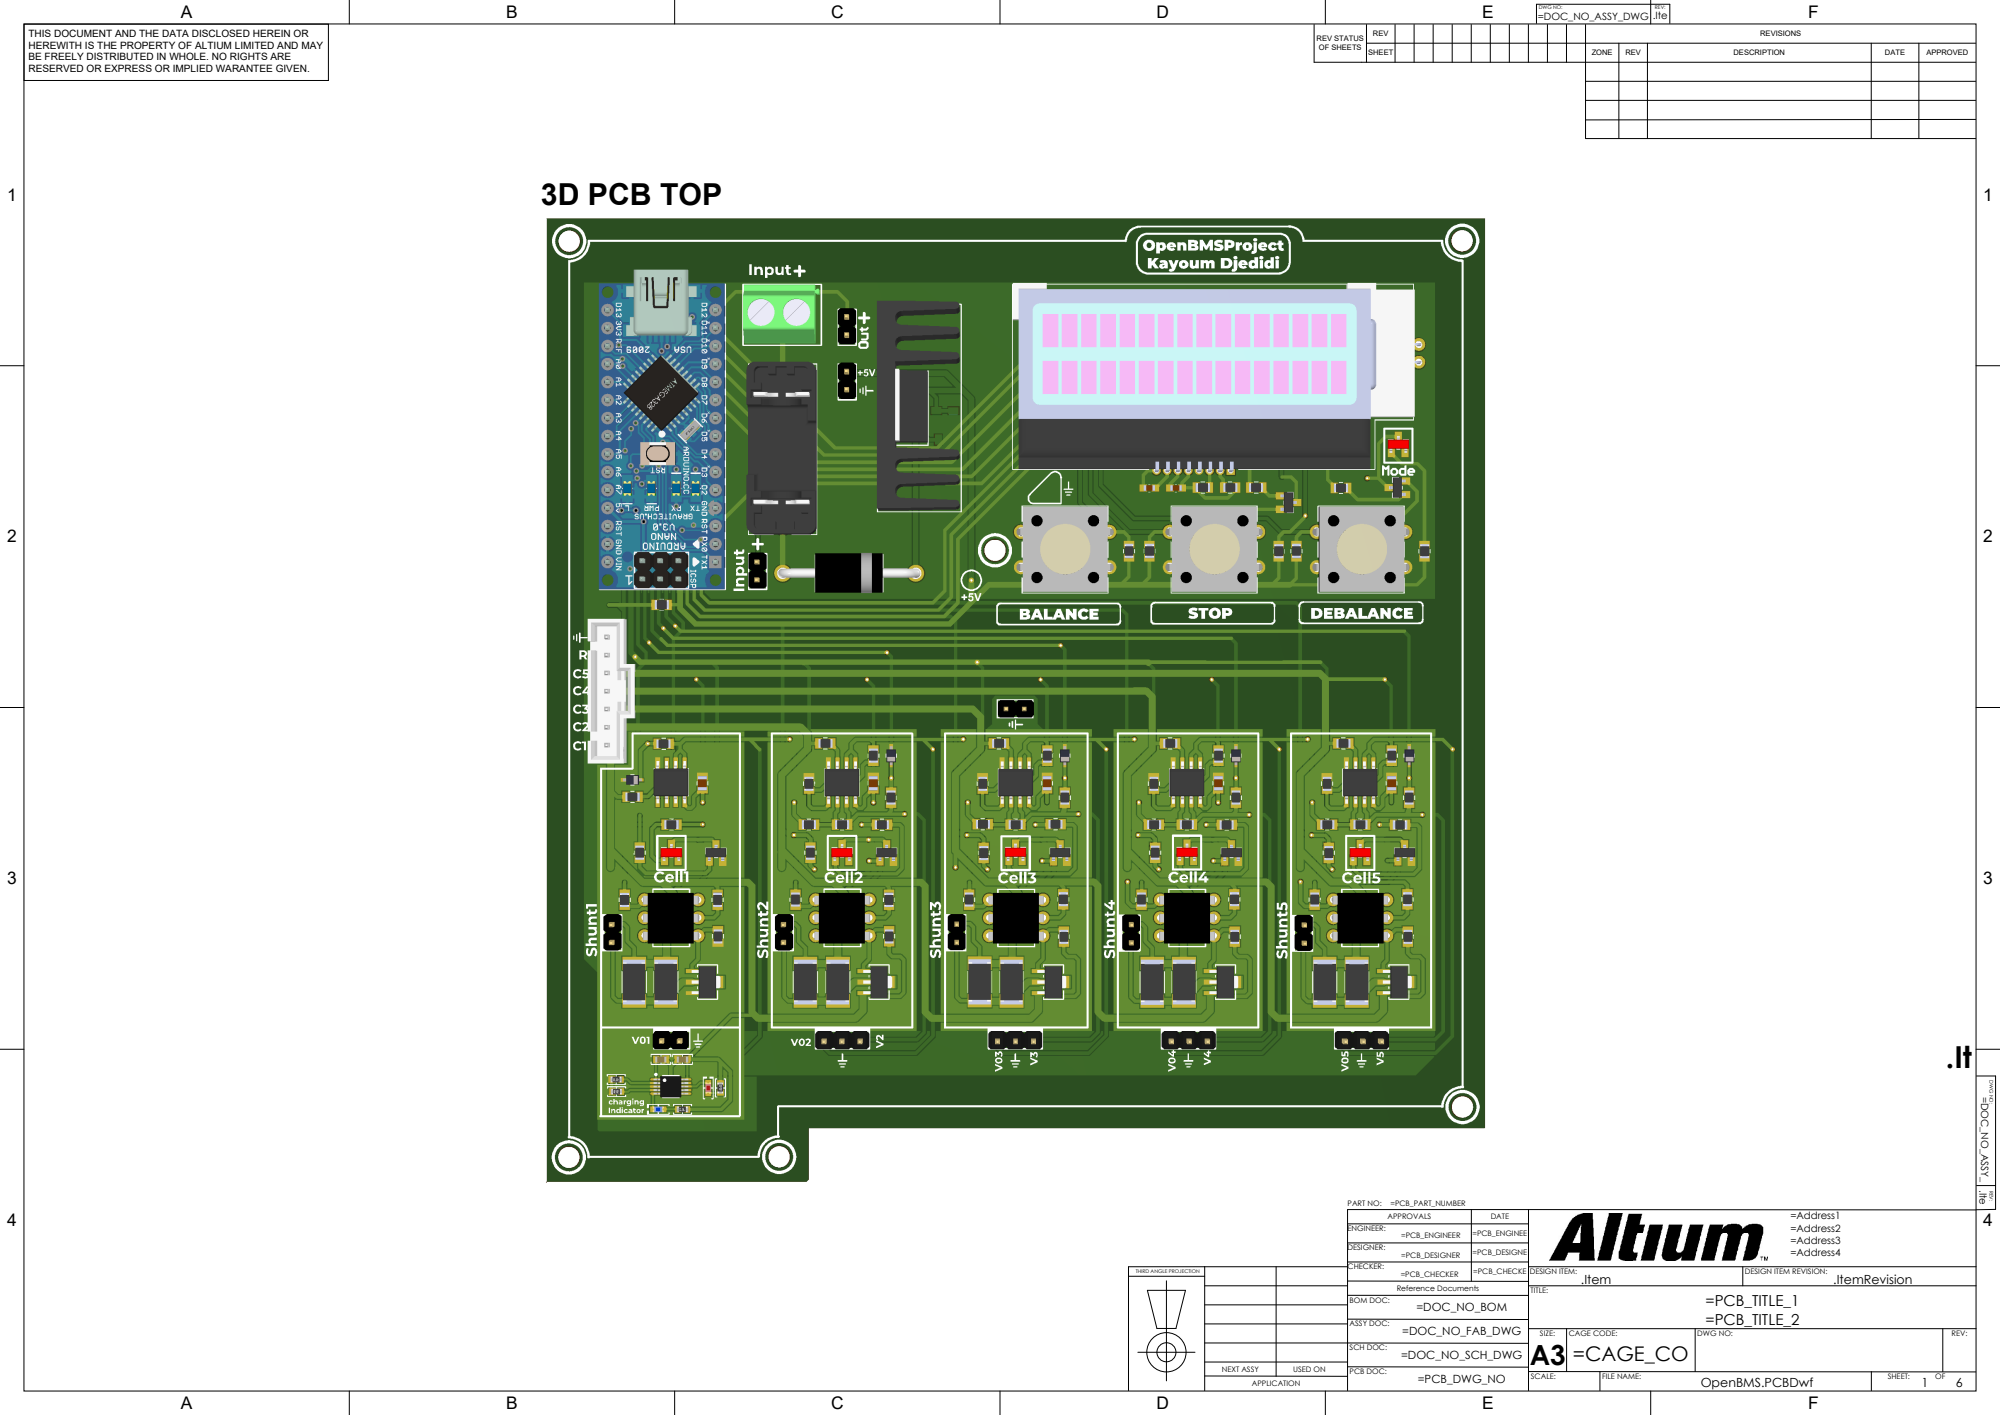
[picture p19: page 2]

THIS DOCUMENT AND THE DATA DISCLOSED HEREIN OR
HEREWITH IS THE PROPERTY OF ALTIUM LIMITED AND MAY
BE FREELY DISTRIBUTED IN WHOLE. NO RIGHTS ARE
RESERVED OR EXPRESS OR IMPLIED WARANTEE GIVEN.

APPROVALS | DATE

ENGINEER: =PCB_ENGINEER | =PCB_ENGINEE

DESIGNER: =PCB_DESIGNER | =PCB_DESIGNE

THIRD ANGLE PROJECTION

CHECKER: =PCB_CHECKER | =PCB_CHECKE

SCH DOC: =DOC_NO_SCH_DWG

NEXT ASSY | USED ON

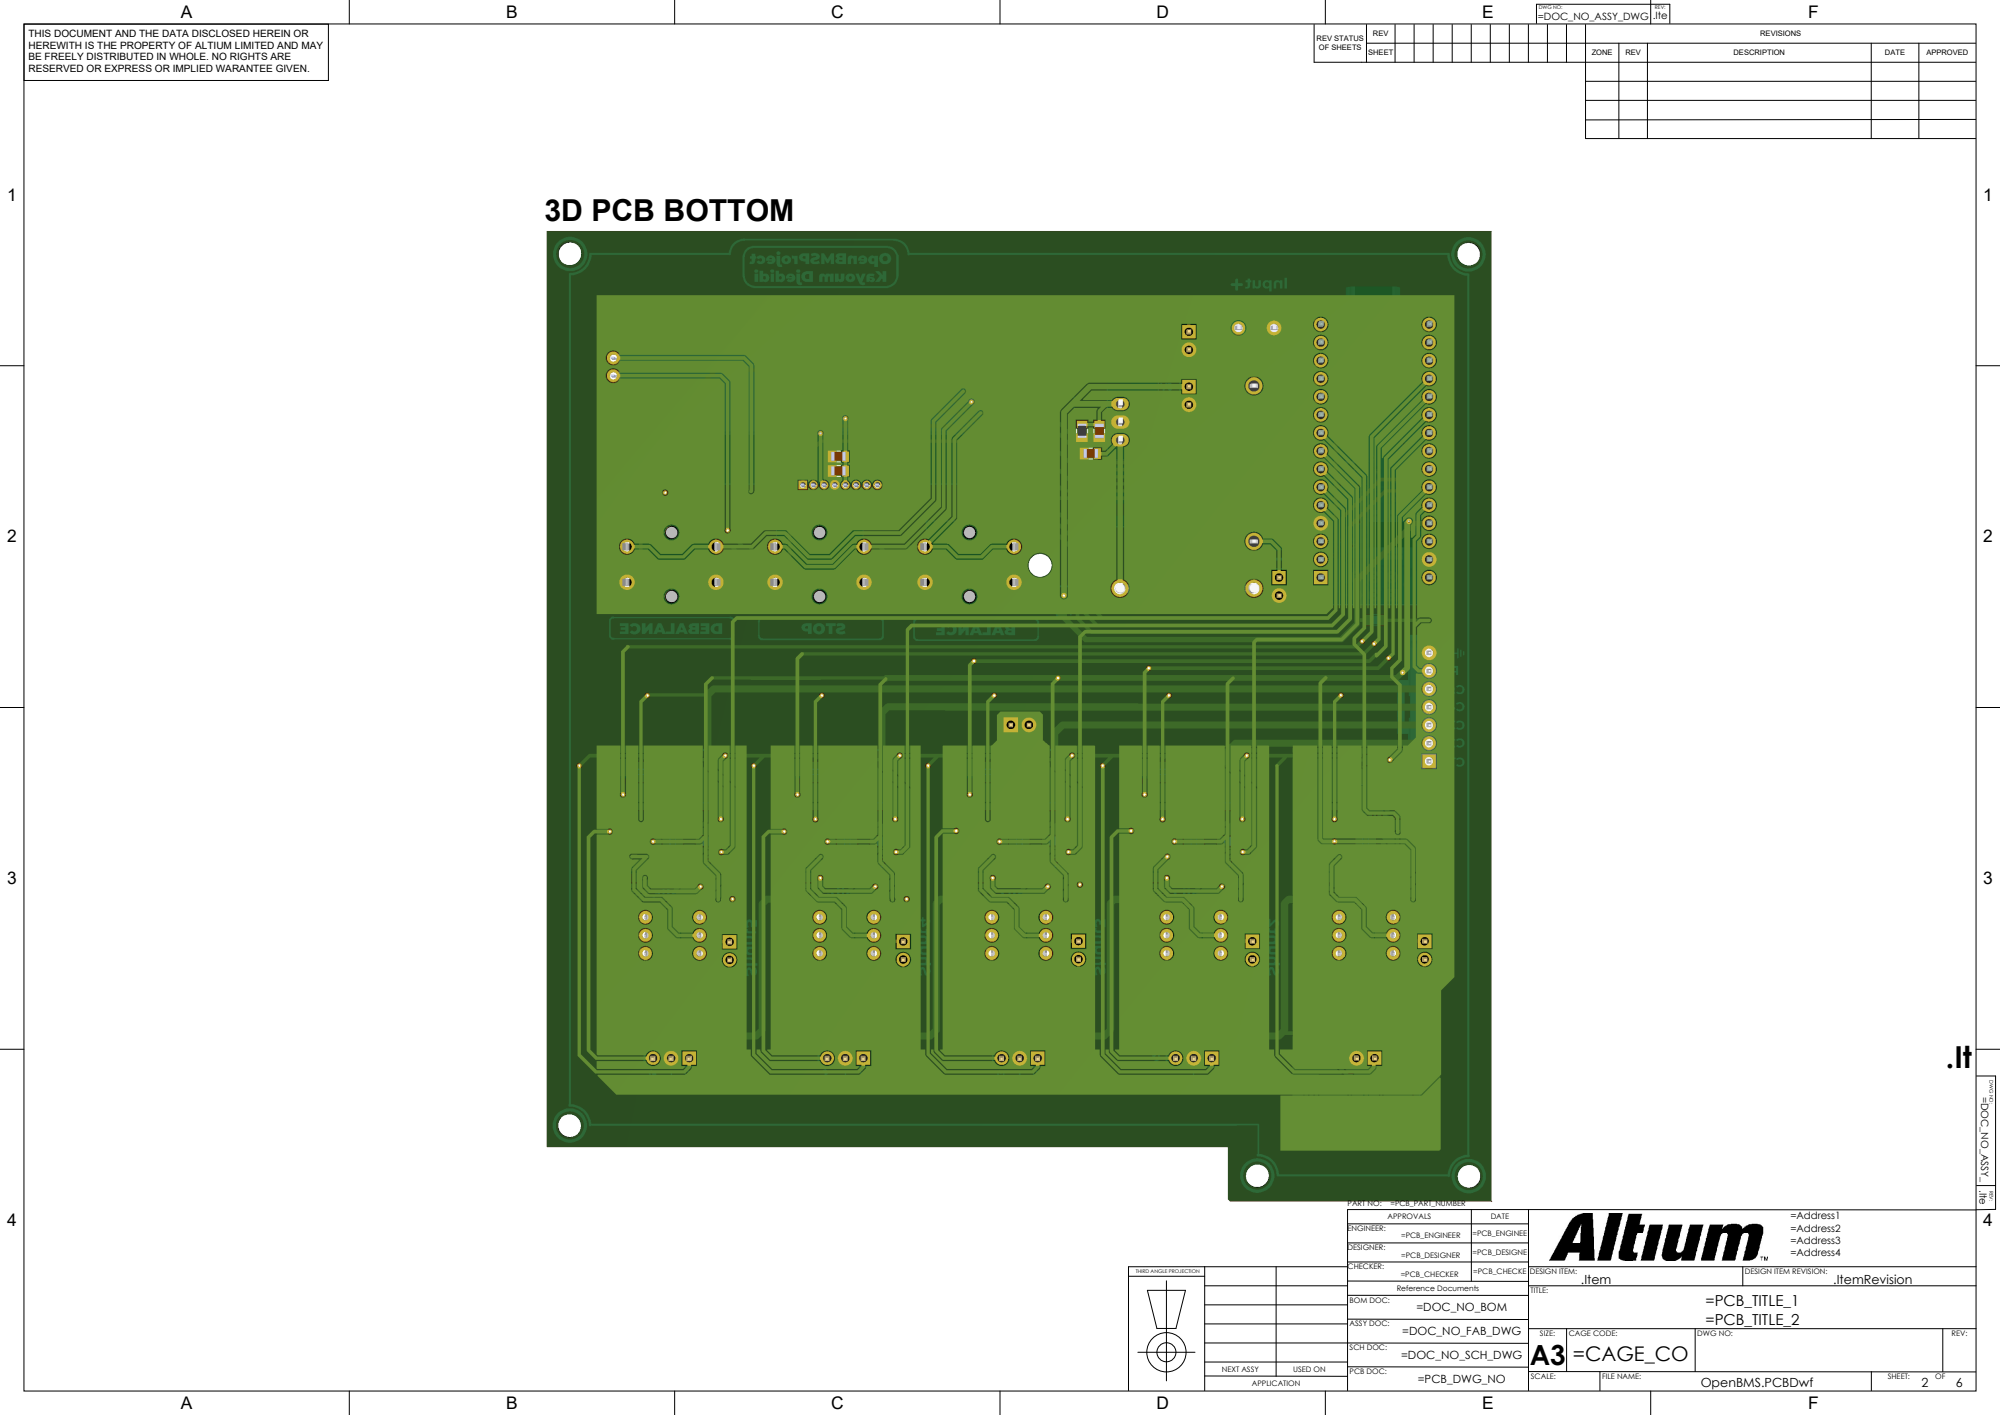
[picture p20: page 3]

APPROVALS | DATE

ENGINEER: =PCB_ENGINEER | =PCB_ENGINEE

DESIGNER: =PCB_DESIGNER | =PCB_DESIGNE

THIRD ANGLE PROJECTION

CHECKER: =PCB_CHECKER | =PCB_CHECKE

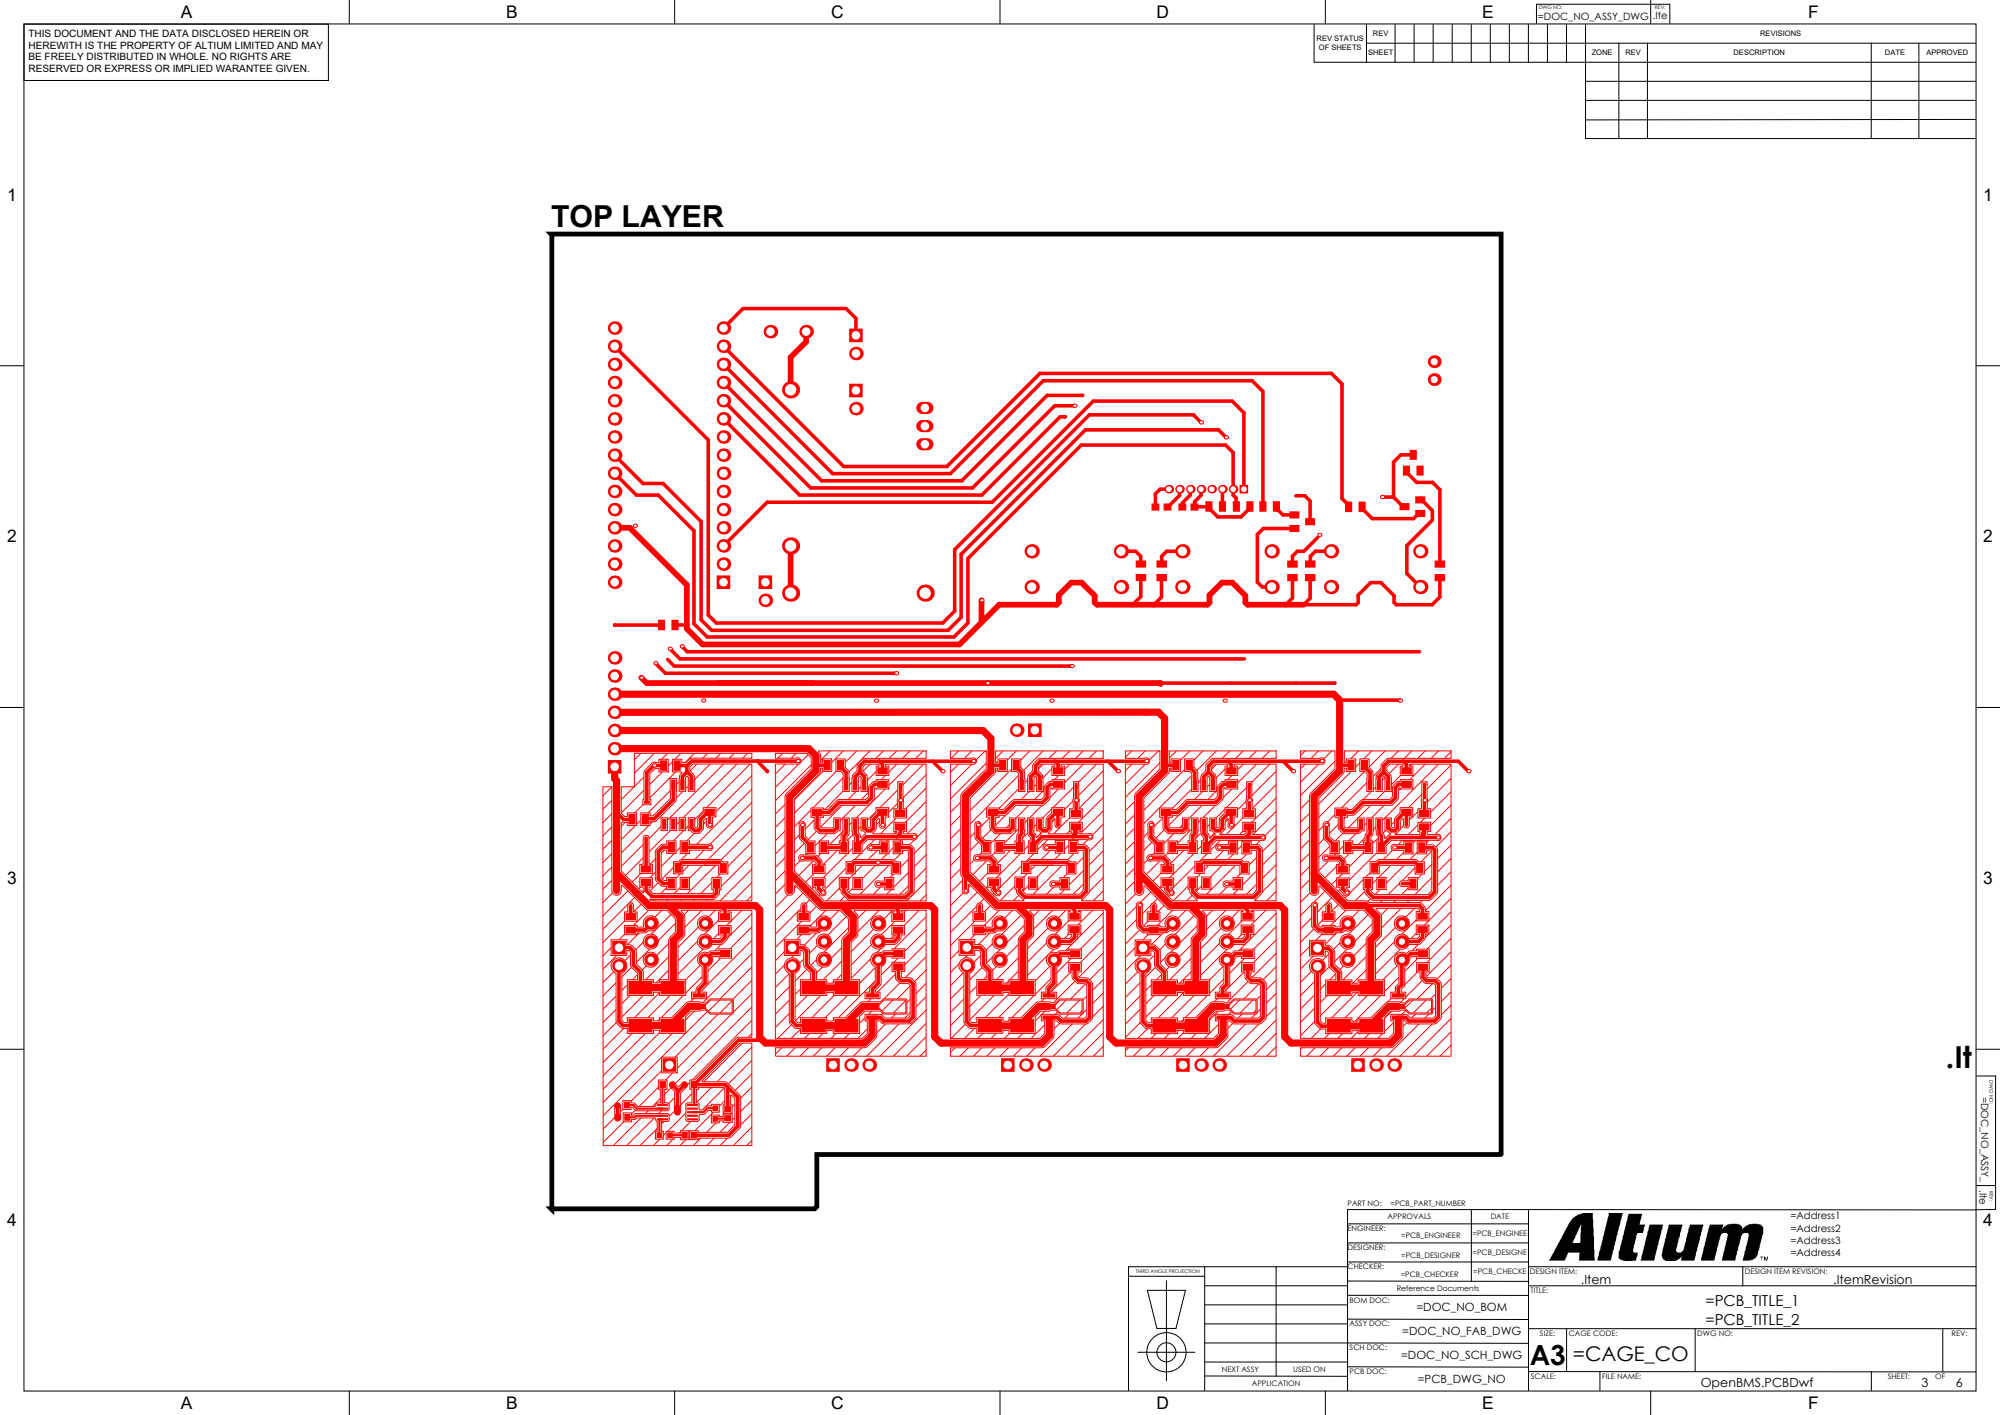
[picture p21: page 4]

APPROVALS | DATE

ENGINEER: =PCB_ENGINEER | =PCB_ENGINEE

DESIGNER: =PCB_DESIGNER | =PCB_DESIGNE

THIRD ANGLE PROJECTION

CHECKER: =PCB_CHECKER | =PCB_CHECKE

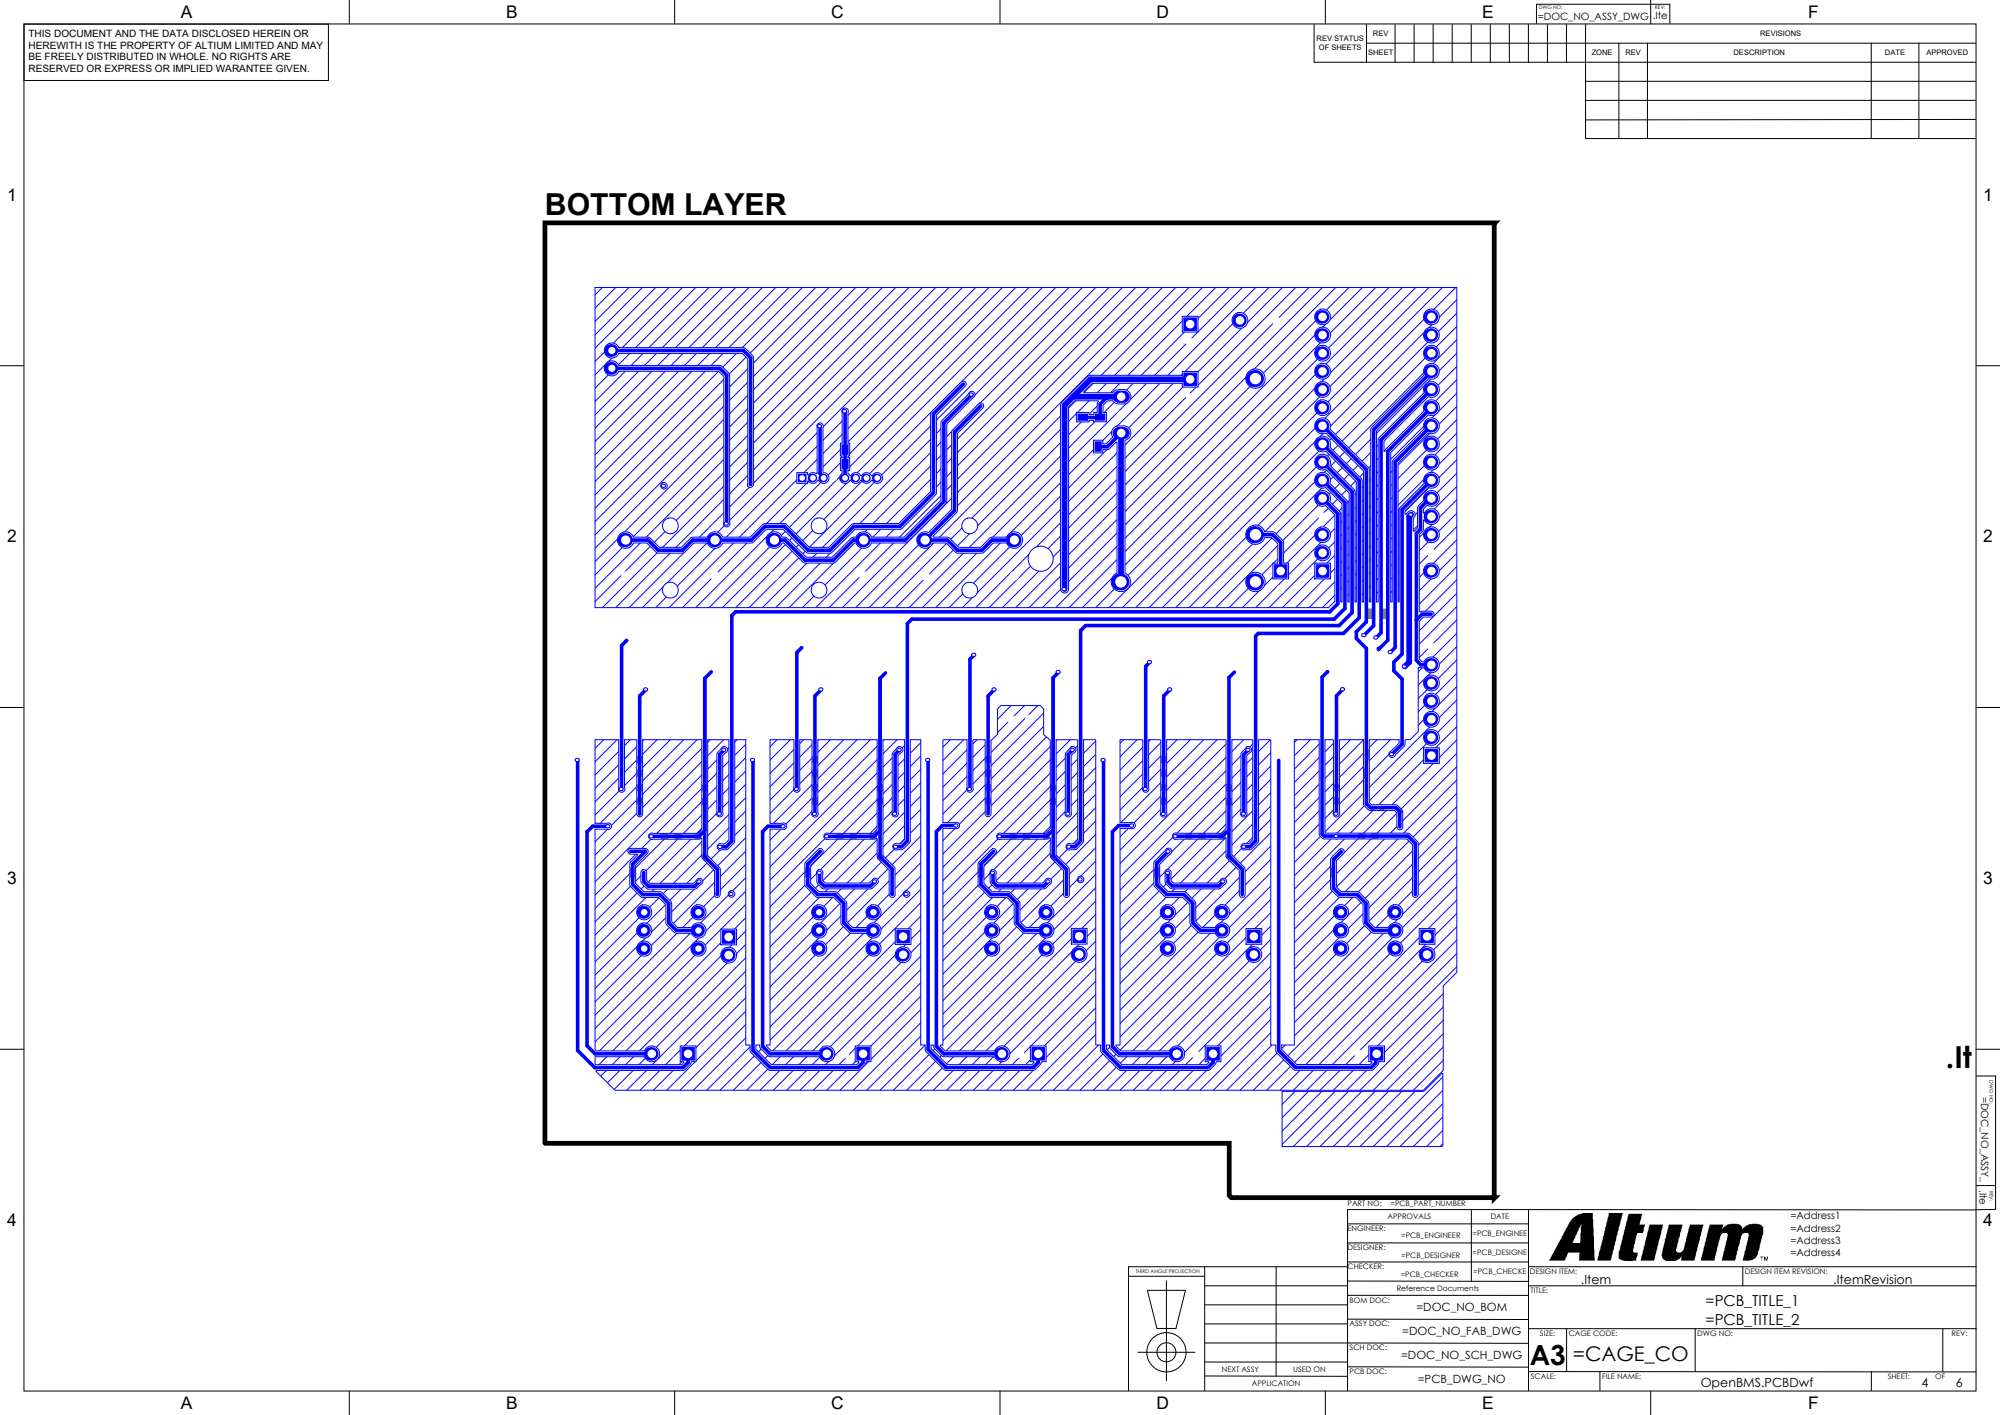
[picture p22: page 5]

APPROVALS | DATE

ENGINEER: =PCB_ENGINEER | =PCB_ENGINEE

DESIGNER: =PCB_DESIGNER | =PCB_DESIGNE

THIRD ANGLE PROJECTION

CHECKER: =PCB_CHECKER | =PCB_CHECKE

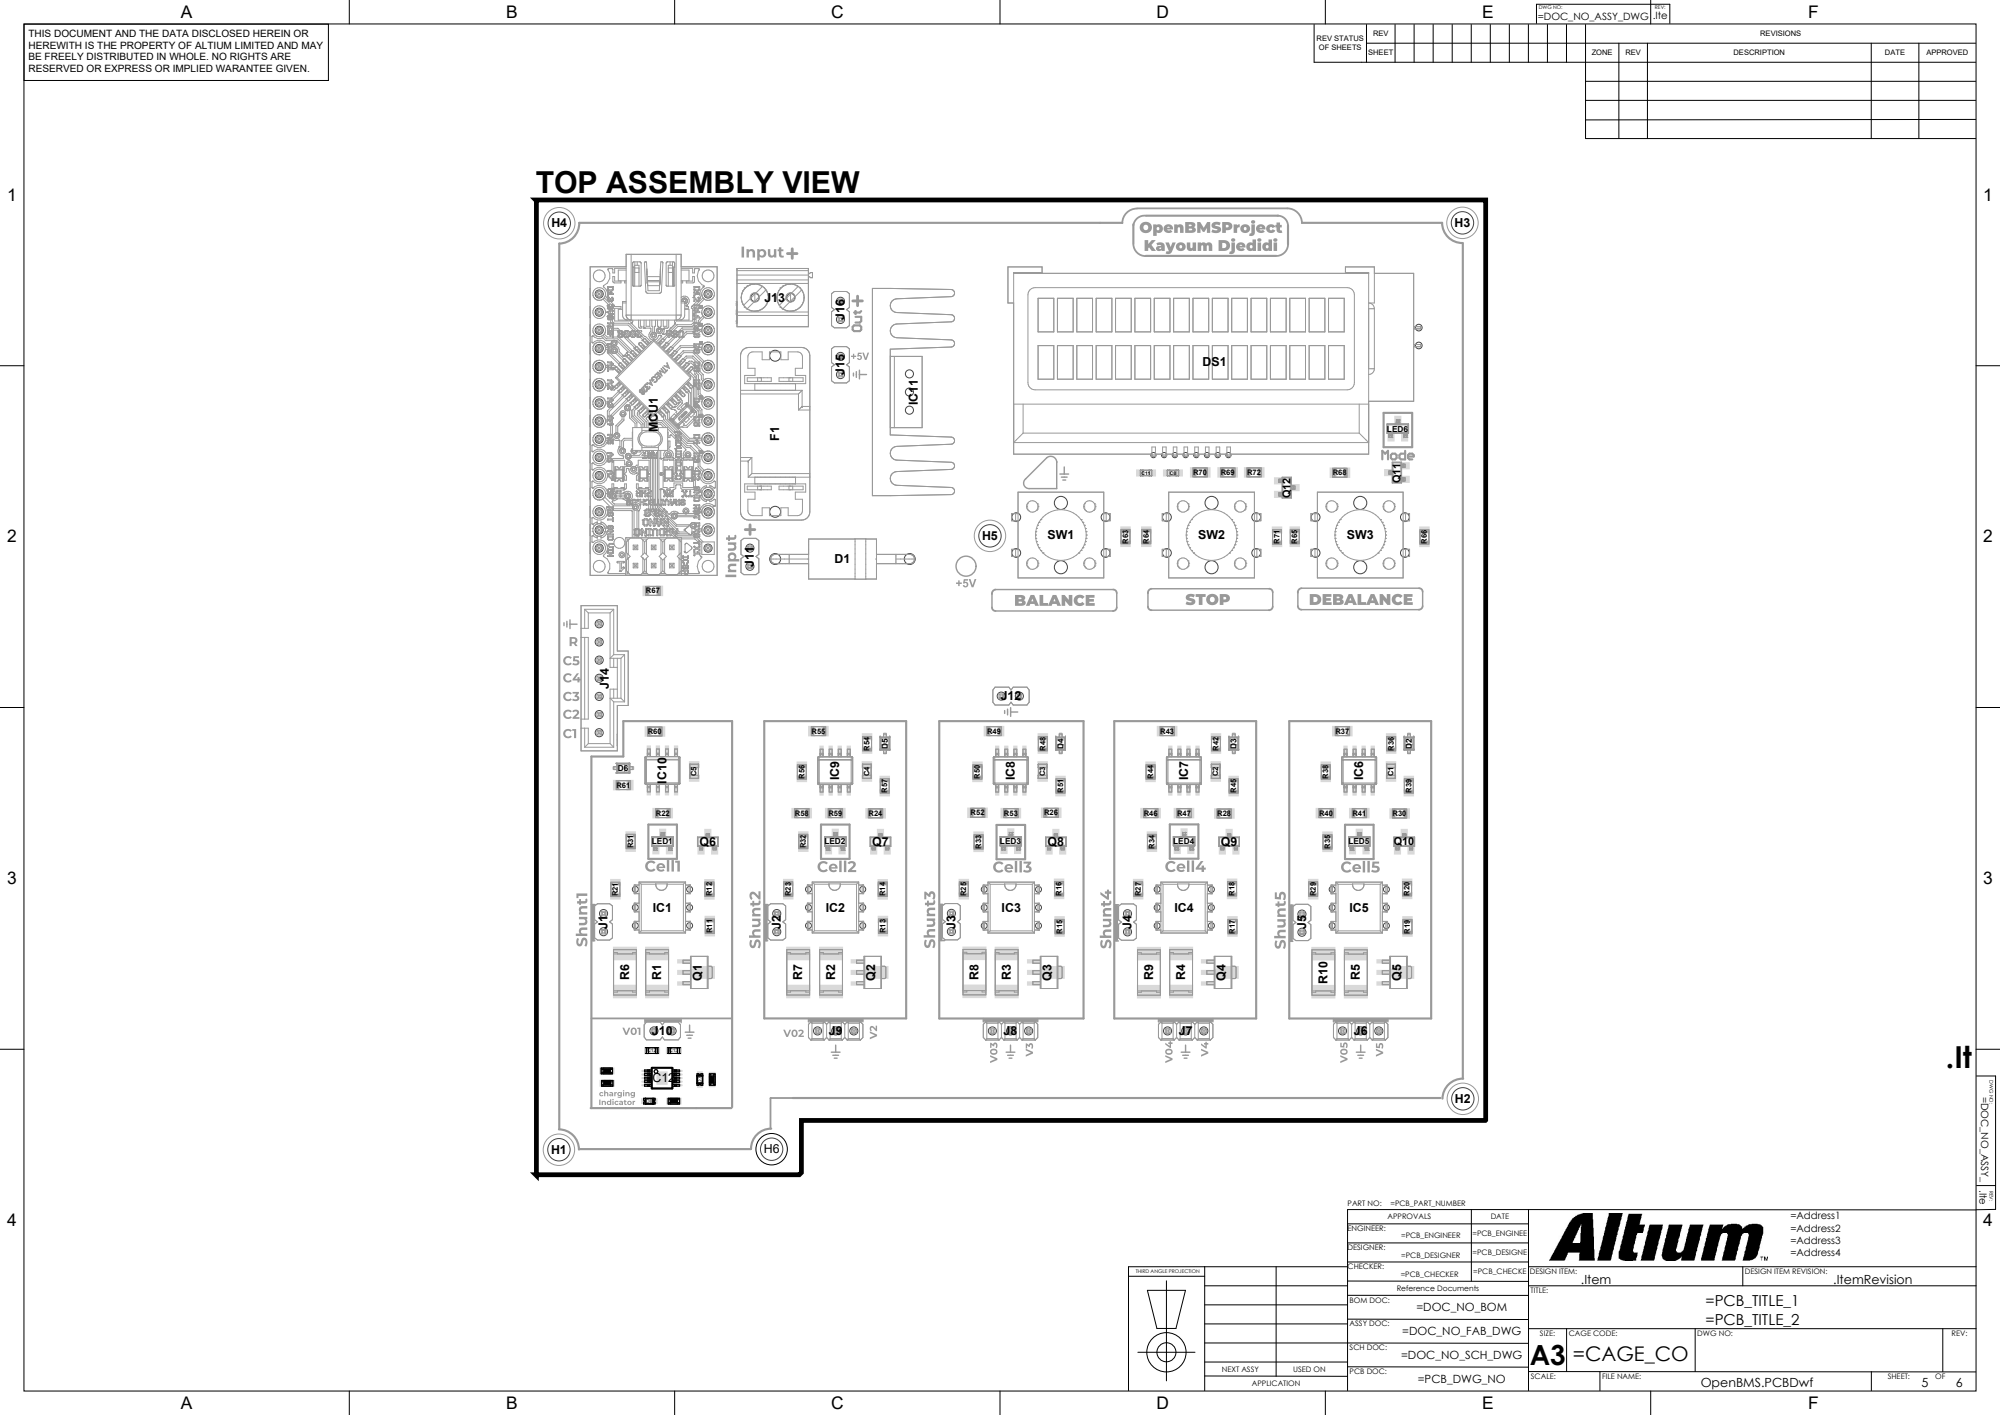
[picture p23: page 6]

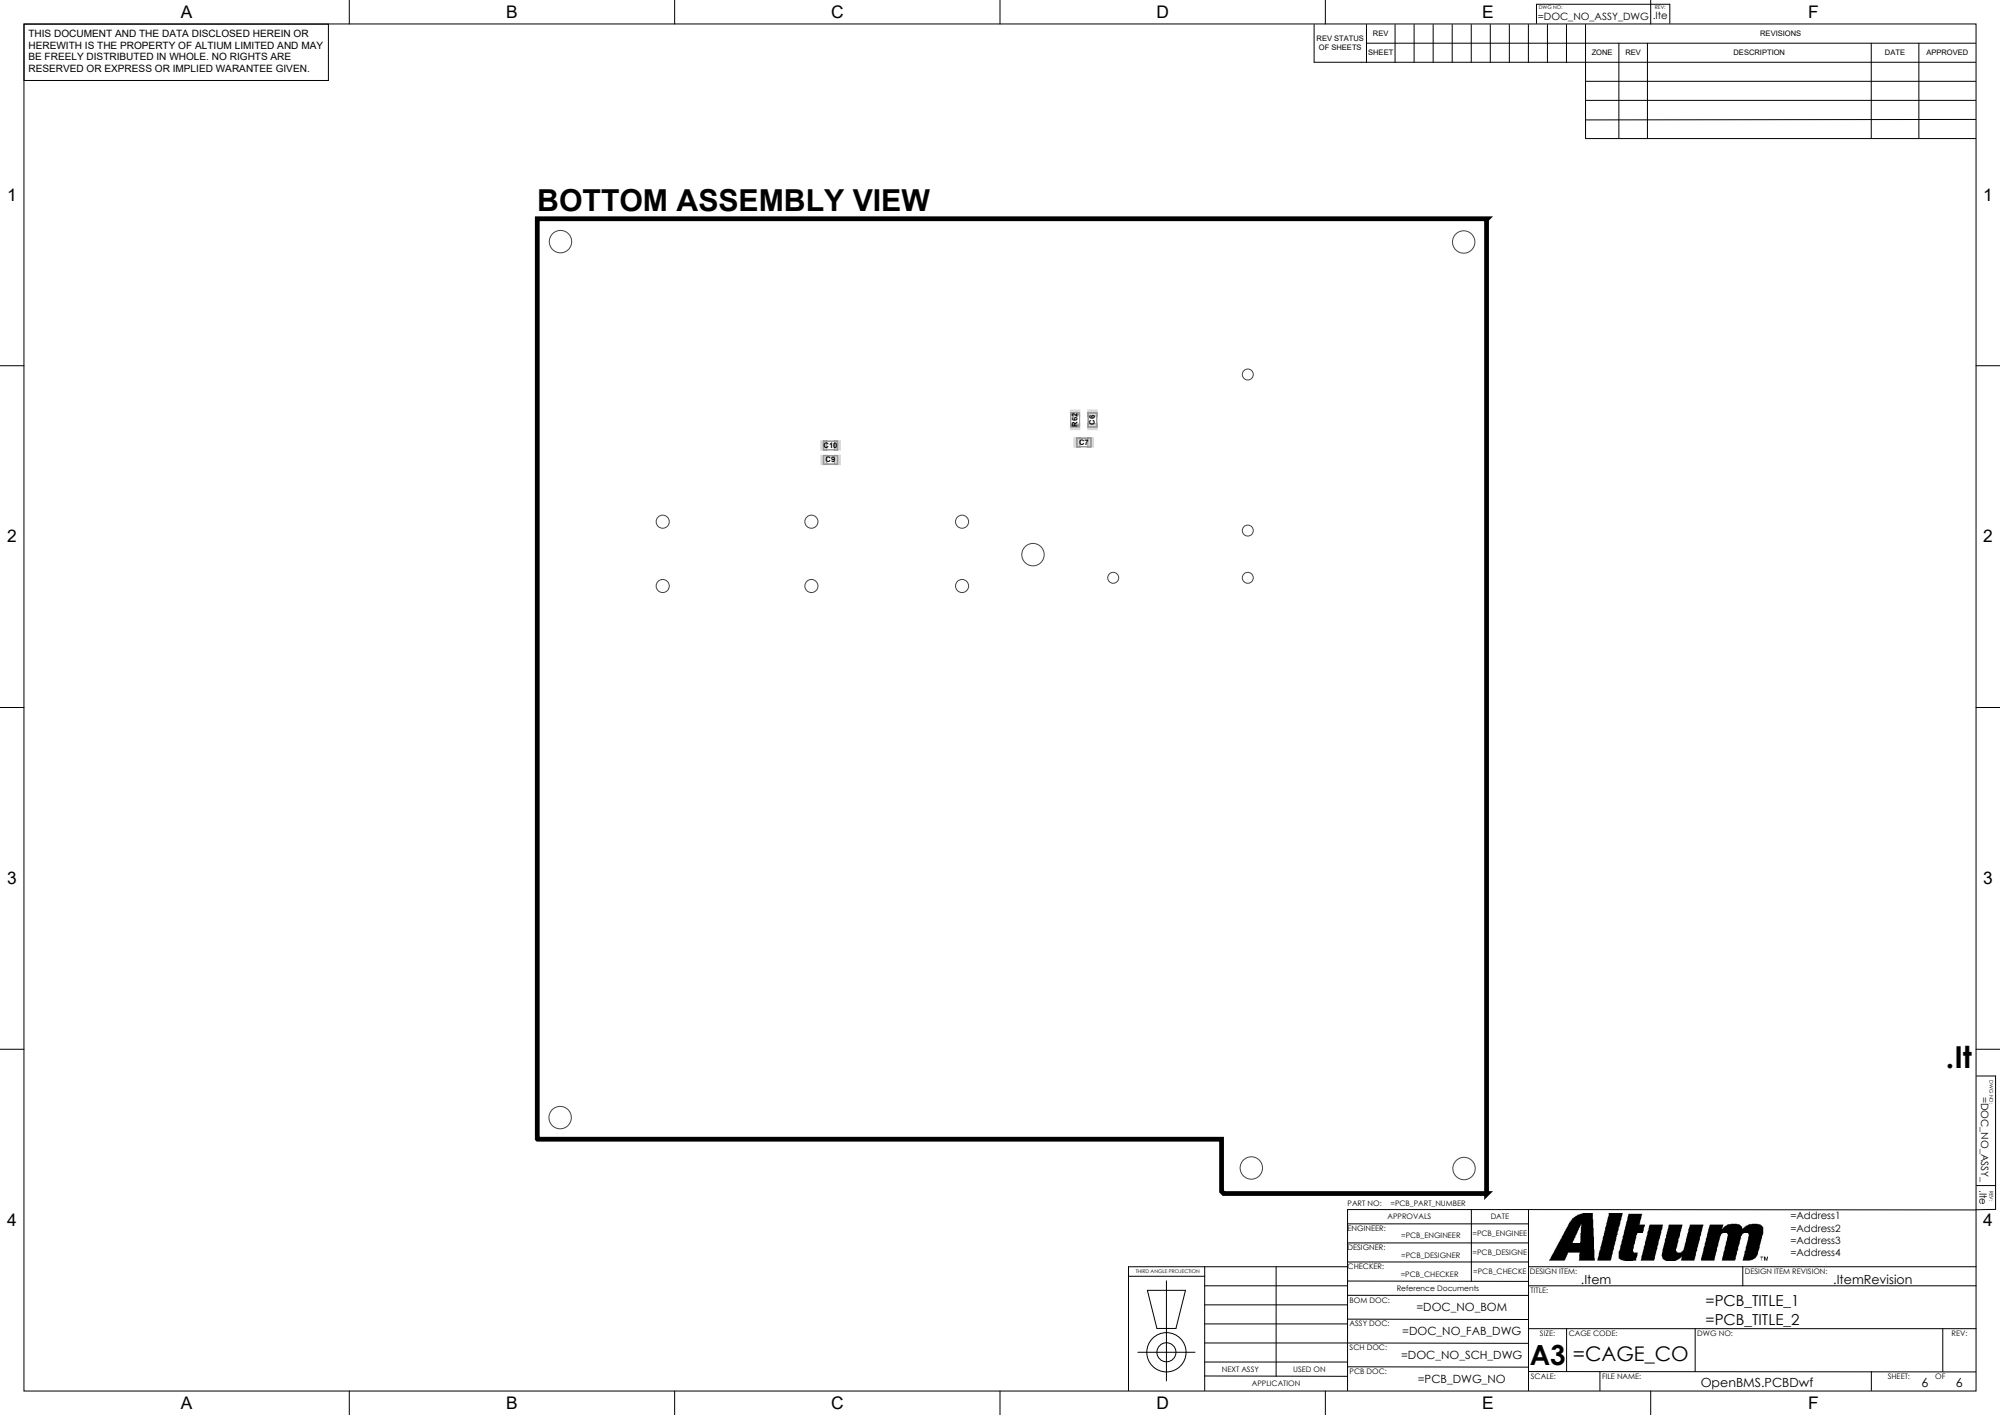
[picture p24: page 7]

APPROVALS | DATE

ENGINEER: =PCB_ENGINEER | =PCB_ENGINEE

DESIGNER: =PCB_DESIGNER | =PCB_DESIGNE

THIRD ANGLE PROJECTION

CHECKER: =PCB_CHECKER | =PCB_CHECKE

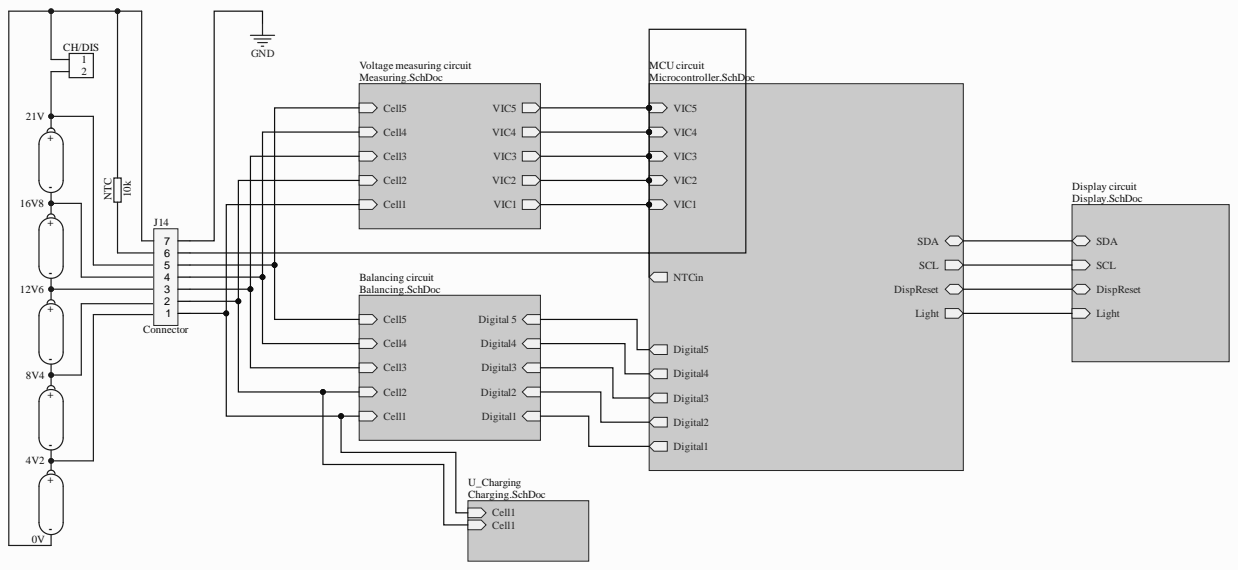
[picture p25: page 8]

REVISION | DESCRIPTION | DATE | APPROVED

DATE | PROJECT OpenBMS | * * APPROVALS * *

ENG: *

DSN: Kayoum Djedidi | --/--/--

CHK: 1 | --/--/--

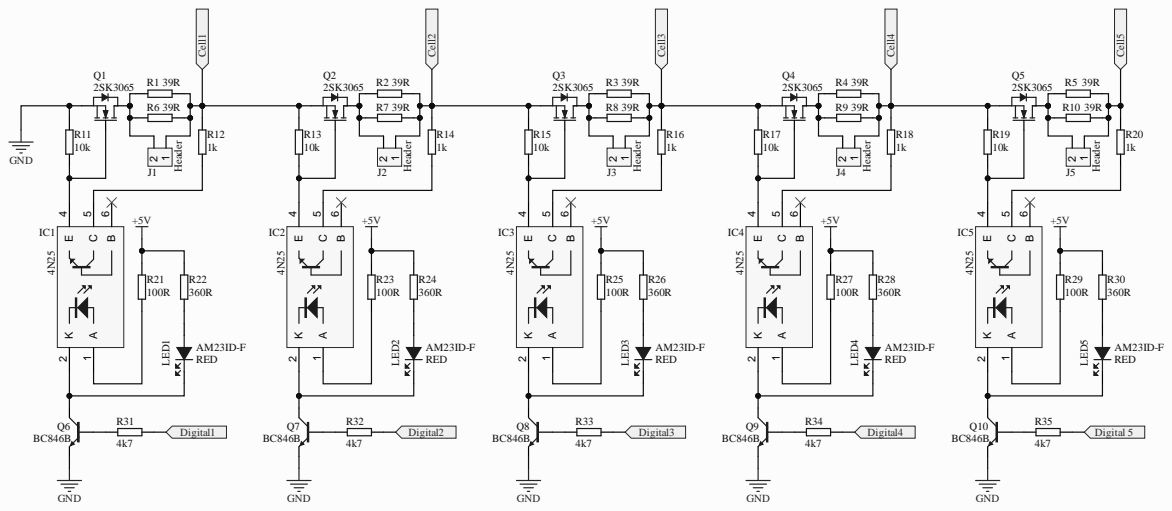
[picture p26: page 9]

REVISION | DESCRIPTION | DATE | APPROVED

DATE | PROJECT * | * * APPROVALS * *

ENG: * | --/--/--

DSN: * | --/--/--

CHK: * | --/--/--

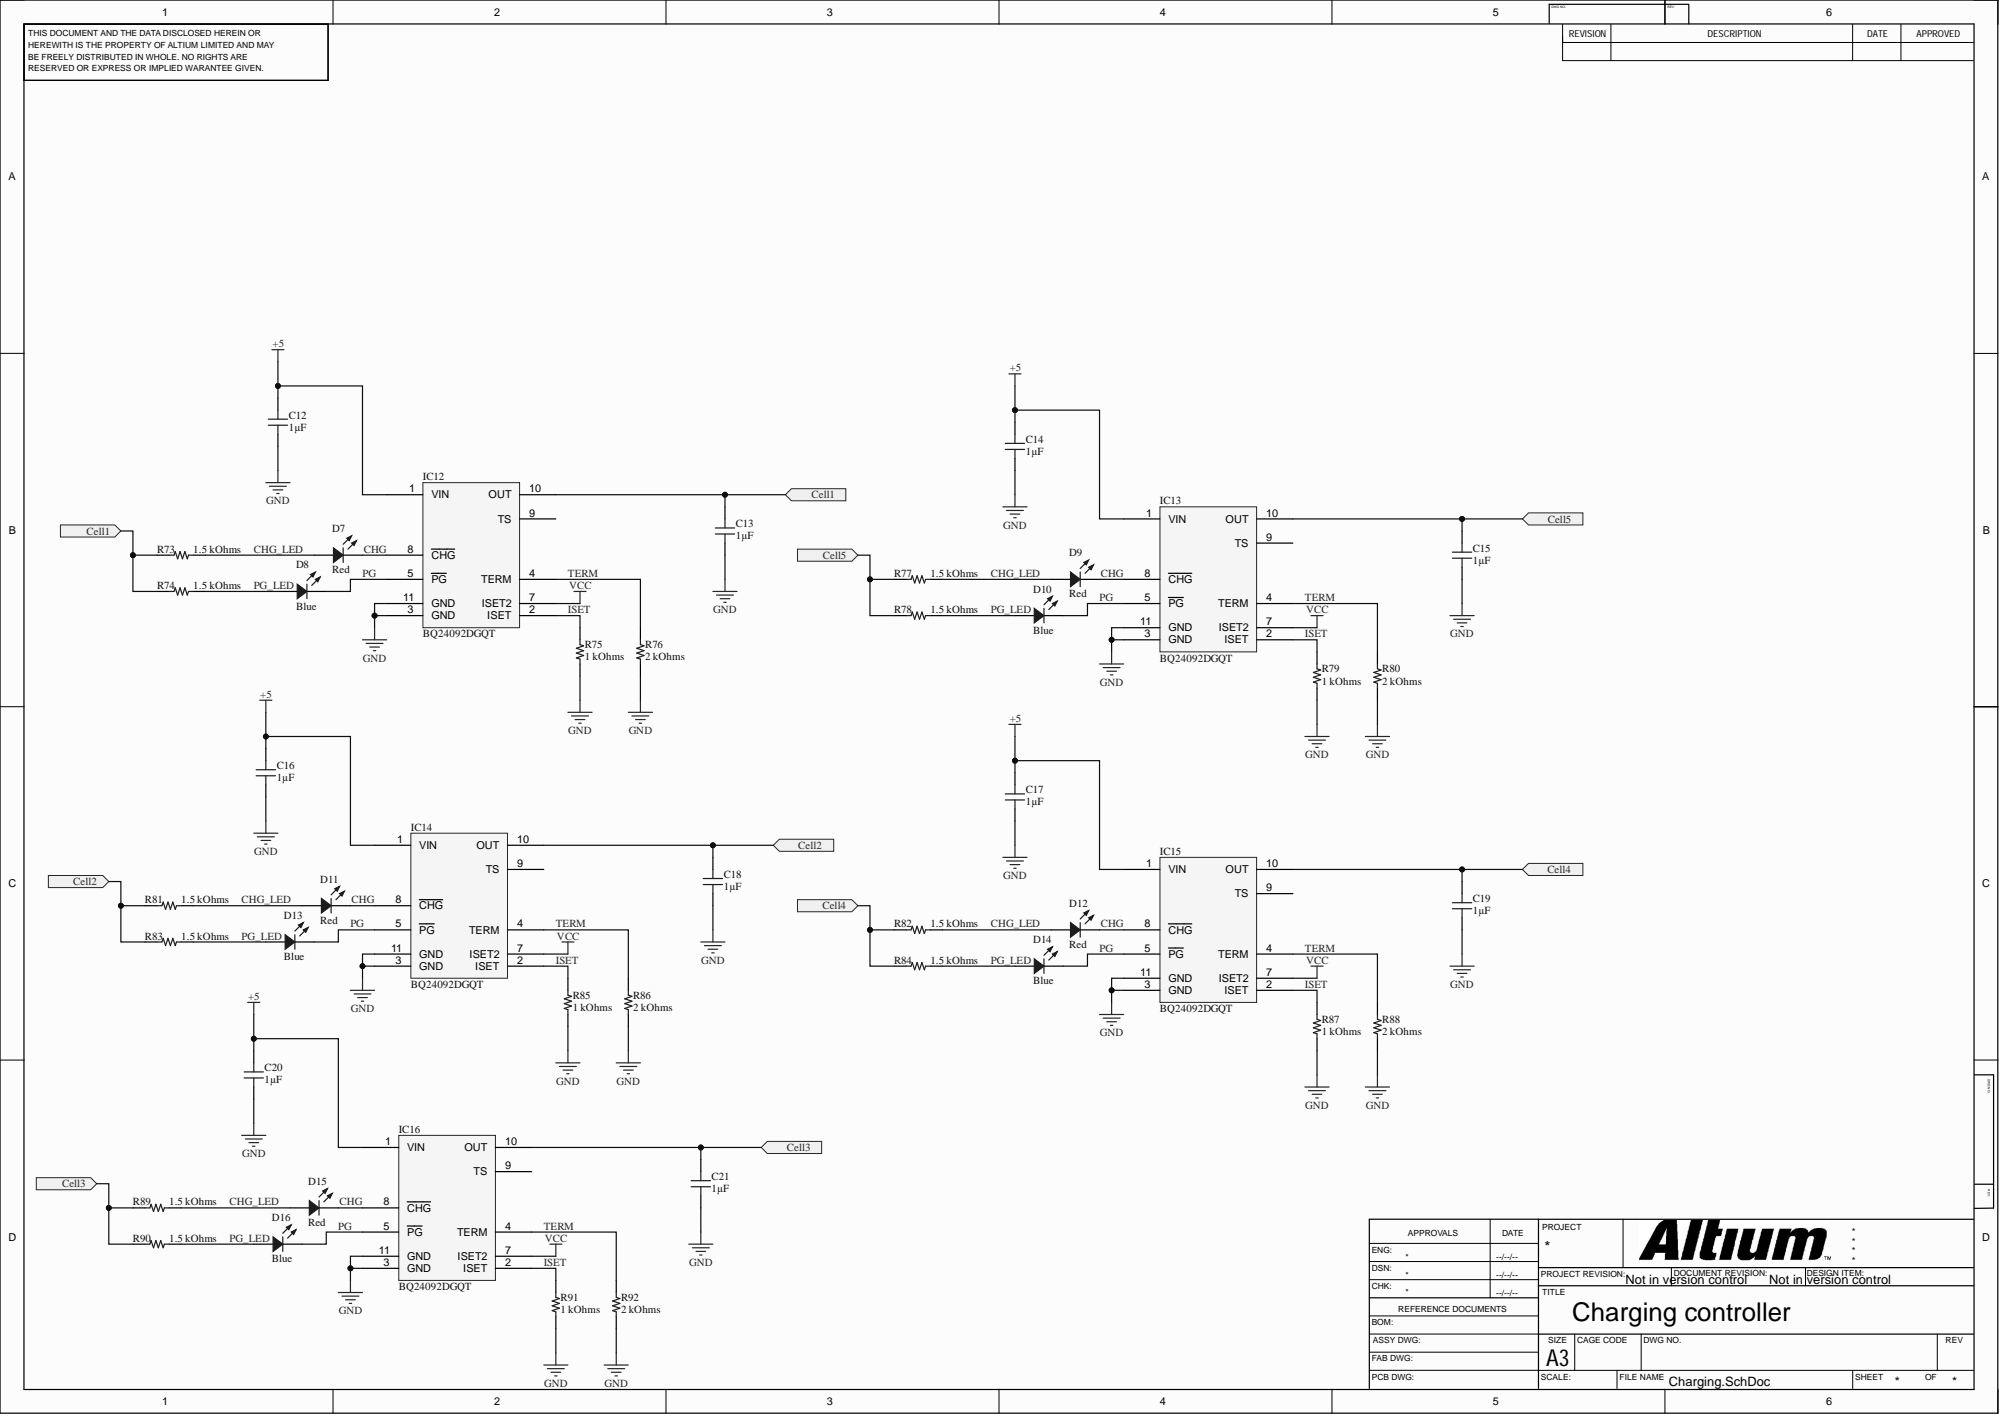
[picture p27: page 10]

THIS DOCUMENT AND THE DA TA DISCL OSED HEREIN O R HEREWITH IS THE PROPERTY OF ALTIUM LIMITED AND M AY BE FREELY DISTRIBUTED IN WHO LE. NO RIGHTS ARE | | REVISI ON | DESCRIPTI O N | DATE | APPROVED

DATE | PRO JECT * | **** APPROVALS

ENG : | --/--/--
** DSN: | --/--/--

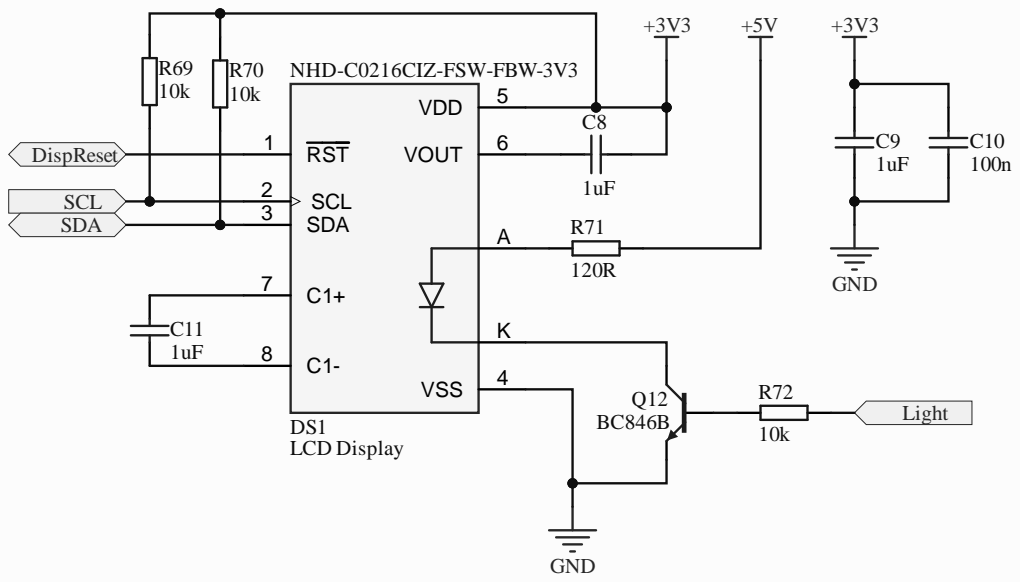
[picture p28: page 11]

REVISION | DESCRIPTION | DATE | APPROVED

DATE | PROJECT * | * * APPROVALS * *

ENG: * | --/--/--

DSN: * | --/--/--

CHK: * | --/--/--

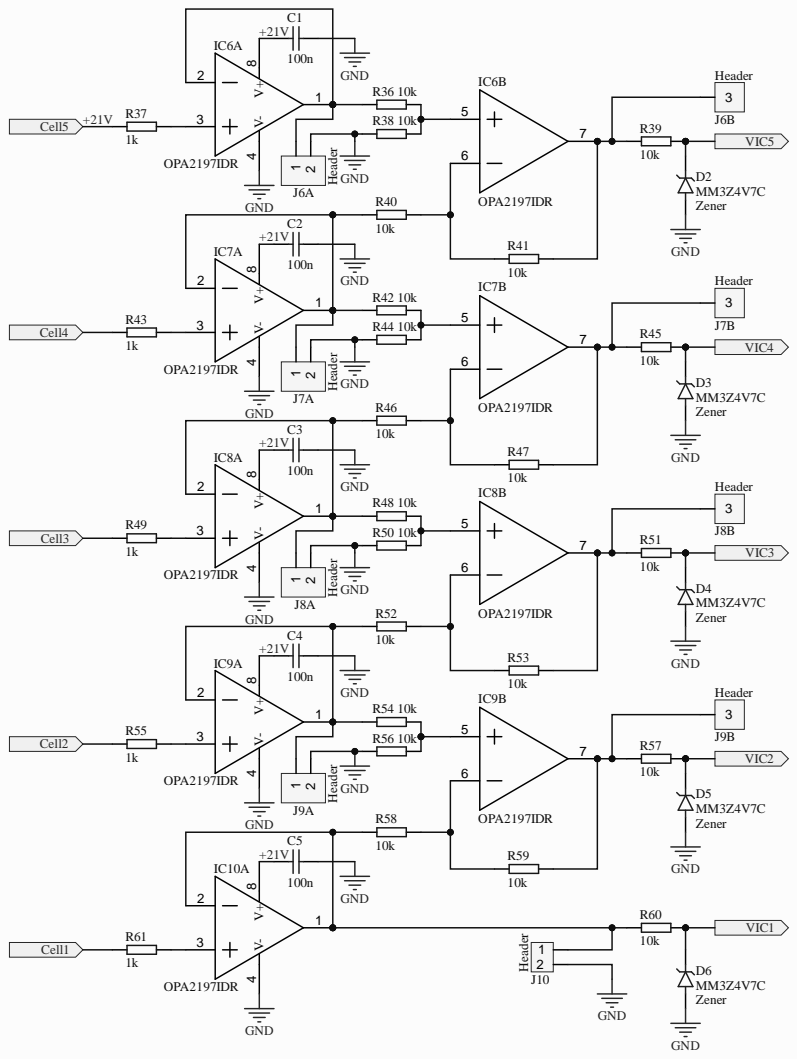
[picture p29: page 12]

REVISION | DESCRIPTION | DATE | APPROVED

DATE | PROJECT * | * * APPROVALS * *

ENG: * | --/--/--

DSN: * | --/--/--

CHK: * | --/--/--

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

D i g i t al 1
D i g i t al 2
D i g i t al 3

DATE | PRO JECT * | **** APPROVALS

ENG : | --/--/--
** DSN: | --/--/--

CHK: * | --/--/--
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

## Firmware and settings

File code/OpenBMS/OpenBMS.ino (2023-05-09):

#include <string.h>
void inputTip(bool*, float*);  //loads push button inputs and sets state variables
void stopp();                  //stops all activity except for voltage measuring and displaying
void warning();                //illuminates warnLED in case of a warning/malfunction
void inputBatt(int*, float*);  //stores analog input voltage values from the battery pack
int maximum(float*);           //finds the index of a battery cell with the greatest voltage
void chargeBatt(float*);       //executes the process of balancing
int minimum(float*);           //finds the index of a battery cell with the lowest voltage
void dischargeBatt(float*);    //executes the process of debalancing
void storage();                //prepares the battery pack for permanent storage
void warnCH(int);              //illuminates warnLED with 50% duty cyle (balance mode)
void warnSTBY();               //intermittently illuminates warnLED with short impulses
void warnDIS(int);             //intermittently illuminates warnLED with long impulses
void displayy();               //outputs parameters onto an LCD screen
void I2C_out(unsigned char);   //sends I2C data towards LCD screen
void I2C_Start();              //initiates I2C data transfer towards LCD screen
void I2C_Stop();               //stops I2C data transfer towards LCD screen
void Show(unsigned char*);     //forwards the message towards function "I2C_out"
void nextline1();              // sets cursor to line 1 on the LCD display
void nextline2();              //sets cursor to line 2 on the LCD display
void init_LCD();               //initializes the LCD display


int i, j;
int tCH, tST, tDIS;                        //variables for push button digital values
float CELL[6];                             //variables for battery cell voltage analog values
bool state[] = { 0, 1, 0, 1, 0 };          //variable for system state/mode {CH, ST, DIS, warning, storage}
unsigned long times1, times2, times3 = 0;  //variables for the delay workaround (system state/mode)
unsigned long wait1, wait2, wait3 = 0;     //variables for the delay workaround (system state/mode)
unsigned long times4, wait4 = 0;           //variables for the delay workaround (safety mode)
unsigned long times5, wait5 = 0;           //variables for the delay workaround (permanent storage mode)
//
unsigned long timesB, waitB = 0;  //variables for the delay workaround (CH&DIS)
//
unsigned long timesA, waitA = 0;  //variables for the delay workaround (warnLED)
unsigned long timesF, waitF = 0;  
unsigned long counter = 0;        //variable for LED counter
bool LEDstate = 1;                //variable for state of the LED
//
bool DIGstate = 0;  //variable for balancing channel state
int index;          //variable for battery cell choice (when balancing/debalancing)
//
bool warningstate = 0;  //variable for safety mode state
int counterACH = 0;     //variable for safety mode counter
//
int counterB = 0;      //variable for debalance counter
int counterStore = 0;  //variable for counter of battery cell voltages greater than cellSTORE
//
unsigned long timesC, waitC = 0;  //variables for the delay workaround (display)
unsigned long timesD, waitD = 0;  //variables for the service menu
unsigned long timesE, waitE = 0;  //variables for LCD display backlight pause during safety mode toggle
//
const char Slave = 0x7C;           //variable for the LCD display
const char Comsend = 0x00;         
const char Datasend = 0x40;        
const char Line1 = 0x02;           
const char Line2 = 0xC0;           
int counterCell = 1;               //variable for battery cell order
bool change = 0;                   //variable for indication of safety mode toggle
char s1[18] = "Passive BMS M.K.";  //LCD intro string (line 1)
char s2[18] = "FERIT 2022      ";  //LCD intro string (line 2)
char s11[18] = "\0";               //variable for intro strings output sign by sign
char a[18] = "\0";                 //string for outputting the first line on the LCD display
char b[18] = "\0";                 //string for outputting the second line on the LCD display
char c[3], d[5] = "\0";            //auxiliary strings for displayy function
//
#define pause1 1000   //press and hold time for balance and debalance modes
#define pause2 10000  //balancing time interval
#define pause3 5000 
#define pause4 5000  //debalancing time interval
#define pause5 30     //warnLED impulse interval, type 2
#define pause6 2500   //warnLED impulse interval, type 3
#define pause7 75     //warnLED impulse interval, type 4
#define pause8 250    //LCD display update rate; backlight pause during safety mode toggle
#define pause9 2000   //vrijeme cekanja za otvaranje servisnog menija
//
#define Vdd 5.025         //real '+5V' bus voltage value
#define cellMAX 4.2       //maximum voltage per Liion battery cell
#define cellMIN 3.7       //minimum voltage per Liion battery cell
#define cellSTORE 3.8     //optimal voltage per Liion battery cell when permanently stored
#define tempMAX 60        //maximum battery pack temperature
#define tempMIN 5         //minimum battery pack temperature
#define correct 1.009     //measured voltage value compensation factor for cell 5
#define TEXT_LCD_SIZE 18  //LCD display font size
#define brightness 128    //LCD display backlight intensity (0255)

int BATT[6] = { A7, A6, A3, A2, A1, A0 };  //declaration of battery pack input pins (cell 1  cell 5, NTC)
                                           //BATT[0] => NTC, BATT[1] => cell 1 ... BATT[5] => cell 5
//
int DIG[6] = { 100, 6, 5, 4, 3, 2 };  //declaration of digital output pins for optocouplers
                                      //DIG[0] => not functional, DIG[1] => cell 1 ... DIG[5] => cell 5
//
int WARN = 11;  //declaration of warnLED pin
//
int TIP[4] = { 101, 7, 8, 9 };  //declaration of push button input digital pins
                                //TIP[0] => not functional, TIP[1] = BALANCE ... TIP[3] = DEBALANCE
//
#define LIGHT 10  //declaration of LCD display backlight pin
#define SDA A4    //declaration of LCD display data pin
#define SCL A5    //declaration of LCD display clock pin
#define RES 3     //declaration of LCD display reset pin

void setup() {

  for (i = 0; i < 6; i++) {  
    pinMode(BATT[i], INPUT);
  }
  //
  for (i = 1; i < 6; i++) {  
    digitalWrite(DIG[i], LOW); 
  }
  //
  pinMode(WARN, OUTPUT);    
  analogWrite(WARN, LOW);   
                             
  for (i = 1; i < 4; i++) {  
    pinMode(TIP[i], INPUT);
  }
  //
  pinMode(LIGHT, OUTPUT);             
  for (i = 0; i < brightness; i++) {  
    analogWrite(LIGHT, i);
    delay(10);
  }
  analogWrite(LIGHT, brightness);
  pinMode(SDA, OUTPUT);  
  pinMode(SCL, OUTPUT);  
  pinMode(RES, OUTPUT);  
                         
  init_LCD();            
  for (i = 0; i < 20; i++) {
    s11[i] = s1[i];
    delay(50);
    nextline1();
    Show(s11);
  }
  delay(300);
  nextline2();
  Show(s2);
  delay(2000);
  //
  Serial.begin(9600);
  //
}

void loop() {

  inputTip(&state[0], &CELL[0]);
  displayy();
  //
  if (state[0] == 1) {
    warnCH();
    chargeBatt(&CELL[0]);
  }
  if (state[1] == 1 && warningstate == 0) {
    stopp();
    if (((tCH == HIGH && tDIS == HIGH) || (tCH == LOW && tST == LOW) || (tDIS == LOW && tST == LOW))) {
      warnSTBY();
    }
    inputBatt(&CELL[0]);
  }
  if (state[2] == 1) {
    warnDIS();
    dischargeBatt(&CELL[0]);
  }
  if (warningstate == 1) {
    warning();
  }
  if (state[4] == 1) {
    storage();
  }
}

void inputTip(bool* state, float* CELL) {

  tCH = digitalRead(TIP[1]);
  tST = digitalRead(TIP[2]);
  tDIS = digitalRead(TIP[3]);
  //
  inputBatt(&CELL[0]);
  //
  times1 = millis();  //balance mode turn on by long pressing push button
  if ((tCH == HIGH) || (tDIS == LOW && tCH == LOW) || (tCH == LOW && tST == LOW)) {
    wait1 = times1;
  }
  if (((times1 - wait1) >= pause1) && (state[1] == 1) && (tDIS == HIGH) && (warningstate == 0)) {
    state[0] = 1;
    state[1] = 0;
    state[2] = 0;
    state[4] = 0;
    counter = 0;
    counterB = 0;
    waitA = timesA;
    waitB = timesB;
    wait1 = times1;
    wait2 = times2;
    wait3 = times3;
  }
  //
  times2 = millis();  //turn off all activity except for voltage measuring and displaying
  if ((tST == HIGH) || (tCH == LOW && tST == LOW && tDIS == LOW)) {
    wait2 = times2;
  }
  if (state[4] == HIGH) {
    if (((times2 - wait2) >= (pause1 / 10))) {
      state[0] = 0;
      state[1] = 1;
      state[2] = 0;
      state[4] = 0;
      warningstate = 0;
      counter = 0;
      DIGstate = 0;
    }
  } else if (((times2 - wait2) >= 20)) {
    state[0] = 0;
    state[1] = 1;
    state[2] = 0;
    state[4] = 0;
    warningstate = 0;
    counter = 0;
    DIGstate = 0;
  }
  //
  times3 = millis();  //debalance mode turn on by long pressing push button
  if ((tDIS == HIGH) || (tDIS == LOW && tCH == LOW) || (tDIS == LOW && tST == LOW)) {
    wait3 = times3;
  }
  if ((times3 - wait3) >= pause1 && state[1] == 1 && tCH == HIGH && warningstate == 0) {
    state[0] = 0;
    state[1] = 0;
    state[2] = 1;
    state[4] = 0;
    counter = 0;
    counterB = 0;
    waitA = timesA;
    waitB = timesB;
    wait1 = times1;
    wait2 = times2;
    wait3 = times3;
  }
  //
  times4 = millis();  //turn on safety mode by long pressing push buttons (balance + debalance)
  if (!((tCH == LOW) && (tDIS == LOW) && (tST == HIGH))) {
    wait4 = times4;
  }
  if ((times4 - wait4) > (3 * pause1)) {
    wait4 = times4;
    state[3] = !state[3];
    warningstate = 0;
    change = 1;
    digitalWrite(WARN, LOW);
    analogWrite(LIGHT, 0);
  }
  //
  times5 = millis();  //turn on permanent storage mode by long pressing all three push buttons
  if (!((tCH == LOW) && (tST == LOW) && (tDIS == LOW))) {
    wait5 = times5;
  }
  if (((times5  - wait5) > (3 * pause1)) && warningstate == 0) {
    wait5 = times5;
    state[0] = 0;
    state[1] = !state[1];
    state[2] = 0;
    state[4] = !state[4];
    counter = 0;
    counterB = 0;
    waitA = timesA;
    waitB = timesB;
    wait1 = times1;
    wait2 = times2;
    wait3 = times3;
  }
}

void stopp() {
  for (i = 1; i < 6; i++) {
    digitalWrite(DIG[i], LOW);
  }
  //
}

void warning() {

  unsigned long timesF = millis();
  //
  stopp();
  //
  if ((timesF - waitF) >= pause7) {  //warnLED flashing
    waitF = timesF;
    LEDstate = !LEDstate;
    digitalWrite(WARN, LEDstate);
  }
}

void inputBatt(float* CELL) {

  CELL[0] = analogRead(BATT[0]);             //battery pack temperature measurement value mapping
  CELL[0] = map(CELL[0], 350, 570, 48, 15);  //    =>    MODIFY THIS VARIABLE
                                             //
  CELL[1] = analogRead(BATT[1]);             //battery cell 1 measuring
  CELL[1] = CELL[1] * (Vdd / 1023);
  //
  CELL[2] = analogRead(BATT[2]);  //battery cell 2 measuring
  CELL[2] = CELL[2] * (Vdd / 1023);
  //
  CELL[3] = analogRead(BATT[3]);  //battery cell 3 measuring
  CELL[3] = CELL[3] * (Vdd / 1023);
  //
  CELL[4] = analogRead(BATT[4]);  //battery cell 4 measuring
  CELL[4] = CELL[4] * (Vdd / 1023);
  //
  CELL[5] = analogRead(BATT[5]);  //battery cell 5 measuring
  CELL[5] = (CELL[5] * (Vdd / 1023)) * correct;
  //
  if (state[3] == 1) {          //error triggering algorithm
    counterACH = 0;             //(triggered if the voltages of *ALL* cells are less than 3.7V
    for (i = 1; i < 6; i++) {   //or if *ANY* of cell's voltages is greater than 4.2V
      if (CELL[i] < cellMIN) {  //or if battery pack temperature value exceeds its rated interval)
        counterACH++;
      }
    }
    for (i = 1; i < 6; i++) {
      if ((CELL[i] >= cellMAX) || (counterACH == 5) || (CELL[0] > tempMAX) || (CELL[0] < tempMIN)) {
        state[0] = 0;
        state[1] = 1;
        if (warningstate == 0) {
          warningstate = 1;
        }
        state[2] = 0;
        counter = 0;
        waitA = timesA;
        waitB = timesB;
        wait1 = times1;
        wait2 = times2;
        wait3 = times3;
      }
    }
  }
}

int maximum(float* CELL) {

  float maxi = 0;
  counterStore = 0;
  //
  for (i = 1; i < 6; i++) {  //counting cells that can be discharged safely
    if (CELL[i] > cellMIN) {
      counterStore++;
    }
  }
  //
  if (counterStore > 0) {
    for (i = 1; i < 6; i++) {  //finding index of a battery cell with the greatest voltage
      if (CELL[i] > maxi) {
        maxi = CELL[i];
        index = i;
      }
    }
  }
  //
  if (counterStore == 0) {  //returning to standby mode
    state[0] = 0;
    state[1] = 1;
  }
  //
  return index;
}

void chargeBatt(float* CELL) {
  unsigned long timesB = millis();
  //
  inputBatt(&CELL[0]);
  //
  if (counterB == 0) {  //initialization of balancing mode
    index = maximum(&CELL[0]);
    digitalWrite(DIG[index], HIGH);
    DIGstate = 1;
    waitB = timesB;
    counterB++;
  }
  //
  if ((timesB - waitB) >= pause2) {  //balancing mode algorithm
    DIGstate = 0;
  }
  if ((timesB - waitB) >= (pause2 + pause3)) {
    index = maximum(&CELL[0]);
    DIGstate = 1;
    waitB = timesB;
  }
  //
  digitalWrite(DIG[index], DIGstate);
}

int minimum(float* CELL) {
  float mini = 10;
  //
  for (i = 1; i < 6; i++) {  //finding index of a battery cell with the lowest voltage
    if (CELL[i] < mini && CELL[i] > cellMIN) {
      mini = CELL[i];
      index = i;
    }
    if (CELL[i] < cellMIN) {
      state[1] = 1;
      state[2] = 0;
      digitalWrite(WARN, HIGH);
    }
  }
  //
  return index;
}

void dischargeBatt(float* CELL) {
  unsigned long timesB = millis();
  //
  inputBatt(&CELL[0]);
  //
  if (counterB == 0) {  //initialization of debalancing mode
    index = minimum(&CELL[0]);
    digitalWrite(DIG[index], HIGH);
    DIGstate = 1;
    waitB = timesB;
    counterB++;
  }
  //
  if ((timesB - waitB) >= pause3) {  //debalancing mode algorithm
    DIGstate = 0;
  }
  if ((timesB - waitB) >= pause3 + pause4) {
    waitB = timesB;
    index = minimum(&CELL[0]);
    DIGstate = 1;
  }
  //
  digitalWrite(DIG[index], DIGstate);
}

void storage() {

  counterStore = 0;
  //
  for (i = 1; i < 6; i++) {  //counting cells that can be discharged safely
    if (CELL[i] > cellSTORE) {
      counterStore++;
    }
  }
  //
  if (counterStore > 0) {  //safe discharge process
    chargeBatt(&CELL[0]);
  }
  //
  if (counterStore == 0) {  //returning to standby mode
    state[4] = 0;
    state[1] = 1;
  }
}

void warnCH() {

  unsigned long timesA = millis();
  //
  if (counter == 0) {  //warnLED initialization
    digitalWrite(WARN, HIGH);
    counter++;
  }
  //
  if ((timesA - waitA) >= pause4) {  //warnLED flashing at "low" frequency at 50% duty cycle
    waitA = timesA;
    LEDstate = !LEDstate;
    digitalWrite(WARN, LEDstate);
  }
}

void warnSTBY() {
  unsigned long timesA = millis();
  //
  do {  //warnLED initialization
    digitalWrite(WARN, LEDstate);
    LEDstate = 1;
    counter++;
  } while (counter = 0);
  //
  if ((timesA - waitA) >= pause5) {  //warnLED flashing at "low" frequency and "low" duty cycle
    LEDstate = !LEDstate;
    digitalWrite(WARN, LOW);
  }
  if ((timesA - waitA) >= (pause5 + pause6)) {
    waitA = timesA;
    LEDstate = !LEDstate;
    digitalWrite(WARN, HIGH);
  }
}

void warnDIS() {

  unsigned long timesA = millis();
  //
  do {  //warnLED initialization
    digitalWrite(WARN, LEDstate);
    LEDstate = 1;
    counter++;
  } while (counter = 0);
  //
  if ((timesA - waitA) >= pause6) {  //warnLED flashing at "low" frequency and "high" duty cycle

    LEDstate = !LEDstate;
    digitalWrite(WARN, LEDstate);
  }
  if ((timesA - waitA) >= ((pause5 * 10) + pause6)) {
    waitA = timesA;

    LEDstate = !LEDstate;
    digitalWrite(WARN, LEDstate);
  }
}

void displayy() {
  unsigned long timesC = millis();
  unsigned long timesD = millis();
  unsigned long timesE = millis();
  //
  if (change == 0) {  //safety mode toggle indication (on/off)  temporary brightness reduction
    waitE = timesE;
  }
  if ((timesE - waitE) > pause8) {
    analogWrite(LIGHT, brightness);
    change = 0;
  }
  //
  if (warningstate == 1) {  //output message: "WARNING!!!  ERROR!!!"
    nextline1();
    Show("   WARNING!!!   ");
    nextline2();
    Show("    ERROR!!!    ");
    waitD = timesD;
  }
  //
  else {  //Service menu parameters output
    if ((!(tCH == HIGH && tST == LOW && tDIS == HIGH))) {
      waitD = timesD;
    }
    if (((timesD -  waitD) >= pause9)) {
      a[0] = 0;
      b[0] = 0;
      strcat(a, "    Temp:");
      if (CELL[0] < (5)) {
        c[0] = 0;
        strcat(c, "??");
      } else {
        dtostrf(CELL[0], 2, 0, c);
      }
      strcat(a, c);
      strcat(a, "C    ");
      strcat(b, "Safety mode: ");
      if (state[3] == 1) {
        strcat(b, "ON ");
      } else {
        strcat(b, "OFF");
      }
    }
    //
    else {  //main parameters output
      a[0] = 0;
      b[0] = 0;
      for (counterCell = 1; counterCell < 4; counterCell++) {
        if (CELL[counterCell] < 2) {
          d[0] = 0;
          strcat(d, "?v??");
        } else {
          dtostrf(CELL[counterCell], 4, 2, d);
          if ((DIGstate == HIGH) && (counterCell == index)) {
            d[1] = 'V';
          } else {
            d[1] = 'v';
          }
        }
        strcat(a, d);
        strcat(a, "  ");
      }
      for (counterCell = 4; counterCell < 6; counterCell++) {
        if (CELL[counterCell] < 2) {
          d[0] = 0;
          strcat(d, "?v??");
        } else {
          dtostrf(CELL[counterCell], 4, 2, d);
          if ((DIGstate == HIGH) && (counterCell == index)) {
            d[1] = 'V';
          } else {
            d[1] = 'v';
          }
        }
        strcat(b, d);
        strcat(b, "  ");
        if (counterCell == 5) {
          if (state[0] == HIGH) {
            strcat(b, " BA ");
          }
          if (state[1] == HIGH) {
            strcat(b, " ST ");
          }
          if (state[2] == HIGH) {
            strcat(b, "DEBA");
          }
          if (state[4] == HIGH) {
            strcat(b, "PERM");
          }
        }
      }
    }
    //
    if ((timesC  - waitC) >= pause8) {  //showing both lines on the LCD display
      waitC = timesC;
      nextline1();
      Show(a);
      nextline2();
      Show(b);
    }
  }
}

void I2C_out(unsigned char j) {

  int n;
  unsigned char d;
  d = j;
  //
  for (n = 0; n < 8; n++) {
    if ((d & 0x80) == 0x80) {
      digitalWrite(SDA, HIGH);
    } else {
      digitalWrite(SDA, LOW);
    }
    d = (d << 1);
    digitalWrite(SCL, LOW);
    digitalWrite(SCL, HIGH);
    digitalWrite(SCL, LOW);
  }
  digitalWrite(SCL, HIGH);
  while (SDA == HIGH) {
    digitalWrite(SCL, LOW);
    digitalWrite(SCL, HIGH);
  }
  digitalWrite(SCL, LOW);
}


void I2C_Start(void) {
  digitalWrite(SCL, HIGH);
  digitalWrite(SDA, HIGH);
  digitalWrite(SDA, LOW);
  digitalWrite(SCL, LOW);
}


void I2C_Stop(void) {
  digitalWrite(SDA, LOW);
  digitalWrite(SCL, LOW);
  digitalWrite(SCL, HIGH);
  digitalWrite(SCL, HIGH);
}


void Show(unsigned char* text) {
  int n;
  //
  I2C_Start();
  I2C_out(Slave);
  I2C_out(Datasend);
  for (n = 0; n < 16; n++) {
    I2C_out(*text);
    ++text;
  }
  I2C_Stop();
}


void nextline1(void) {

  I2C_Start();
  I2C_out(Slave);
  I2C_out(Comsend);
  I2C_out(Line1);
  I2C_Stop();
}

void nextline2(void) {
  I2C_Start();
  I2C_out(Slave);
  I2C_out(Comsend);
  I2C_out(Line2);
  I2C_Stop();
}

void init_LCD() {

  I2C_Start();
  I2C_out(Slave);
  I2C_out(Comsend);
  //
  I2C_out(0x38);
  I2C_out(0x39);
  I2C_out(0x14);
  I2C_out(0x78);
  I2C_out(0x5E);  
  I2C_out(0x6B);  
  I2C_out(0x0C);
  I2C_out(0x01);
  I2C_out(0x06);
  //
  I2C_Stop();
  I2C_out(0x01);
}
